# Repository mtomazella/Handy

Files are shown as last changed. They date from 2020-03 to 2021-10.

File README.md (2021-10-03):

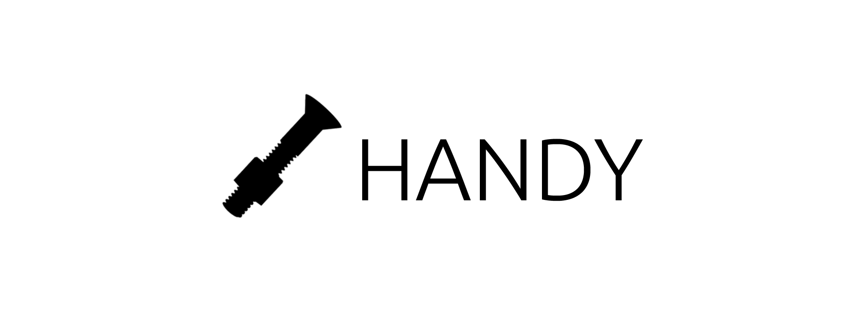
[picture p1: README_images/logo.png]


<p align="center"> Prótese são muito caras, frequentemente fazendo com que pessoas com membros amputados não tenham condições de pagar por uma. O objetivo do projeto é criar uma solução barata para o cliente, a fim de que possa melhorar sua qualidade de vida até conseguir uma prótese mais tecnológica. </p>

### [Documentação](https://github.com/MatheusTomazella/Handy/blob/master/Documentação/Documentação.pdf)
### [Repositório API](https://github.com/matheustomazella/pinus)  
### [Repositório Web](https://github.com/MatheusTomazella/Handy-Web)
### [Repositório Mobile](https://github.com/matheustomazella/handy-mobile)
### [Repositório Desktop](https://github.com/matheustomazella/handy-desktop)
### [Repositório Firmware](https://github.com/MatheusTomazella/Handy-Firmware)
### [Trello](https://trello.com/b/jp3Bz9N3/tcc)

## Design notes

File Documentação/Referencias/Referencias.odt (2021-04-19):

Hand Design:

https://github.com/ikkalebob/NM-bionic-hand

https://www.youtube.com/channel/UCkUD_8b1JoTL2ipOVtxfNKw

Muscle Contraction Sensor

https://www.mdpi.com/1424-8220/18/8/2553/htm

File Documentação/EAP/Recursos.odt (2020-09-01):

# Ferramentas

• Impressora 3d;

• Multímetro.

# Recursos Construção Mecânica

• 9x Parafuso M4 cabeça chata 20mm;

• 1x Parafuso M4 cabeça chata 26mm;

• 1x Parafuso M4 cabeça chata 90mm;

• ?m Filamento ??

# Recursos Construção Eletrônica

N = número de controles

• (N+1)x Arduino Mini 3.3v (modelo Pro opcional);

• (N+1)x Placa de proteção de bateria 18650 BMS 1 S 3 A 4.2v;

• (N+1)x Módulo de rádio nRF24;

• 1x Módulo Bluetooth hc 06 ou hc 05;

• 5x Motor DC;

• 5x Transistor NPN que suporte 8.4v e 2A (opção: BC368);

• 3x Resistor 220Ohms;

• (N+1)x Conector para fonte de celular;

• Chave Táctil (Push Button);

• Baterias Li-ion 18650;

• Conversor USB Serial TTL.

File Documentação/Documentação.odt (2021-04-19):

HANDY

DOCUMENTAÇÃO

v 2020.09.20

Matheus Tomazella

Luiz Felipe Costa Soares

Eduardo Gomes Heleno

# 1 TERMOS DE ABERTURA

## 1.1 JUSTIFICATIVA DO PROJETO

Muitas vezes prótese são muito caras, levando pessoas com membros amputados a não terem condições de pagar por uma. O objetivo do projeto é criar uma solução barata para o cliente, a fim de que possa melhorar sua qualidade de vida até conseguir uma prótese mais tecnológica.

## 1.2 DESCRIÇÃO DO PROJETO

A ideia principal dessa prótese é a acessibilidade, possibilitando que mais camadas da sociedade tenham condições de possuir uma prótese para seus membros amputados. O produto é pensado para confecção em impressoras 3d, porém pode ser construído segundo a vontade do cliente, e deve ser controlado por movimentos de outras partes do corpo.

Uma página web será criada para compartilhar informações sobre o produto e permitir que interessados se comuniquem com os criadores.

O produto possuirá um software para desktop, para acessar os dados enviados por interessados no projeto por meio do site e um software mobile configuração da prótese.

## 1.3 GERENTE DO PROJETO

MATHEUS TOMAZELLA

### 1.3.1 Nível de Autoridade

O gerente de projeto deve ter autoridade para coordenar recursos financeiros e humanos disponibilizados, a fim de concluir o projeto.

## 1.4 PATROCINADOR

Grupo responsável pelo projeto.

## 1.5 PARTES INTERESSADAS

1. Cliente;
2. Projetista;
3. Designer;
4. Programador.

## 1.6 RESTRIÇÕES

1. Não existe um orçamento máximo fixo para o projeto, porém deve usar o mínimo possível de recursos financeiros;
2. O projeto deve possuir uma versão totalmente funcional até o final do ano de 2021.

## 1.7 PREMISSAS

1. Deve priorizar um produto final barato;
2. O produto deve poder ser construído pelo cliente.

## 1.8 AUTORIZAÇÃO DO PROJETO

Data: 01 de Setembro de 2020

______________________________________

Matheus Tomazella

# 2 DETALHAMENTO DE REQUISITOS

## 2.1 ENGENHARIA DA PRÓTESE

### 2.1.1 Funcionamento da prótese

O movimento da prótese é baseado em fios que correm entre os dedos, ligando a parte mais extrema de cada dedo com seu correspondente atuador. Uma vez que o atuador puxa o fio, a ponta do dedo será puxada e o levará a se dobrar contra a palma, assim como uma mão biológica.

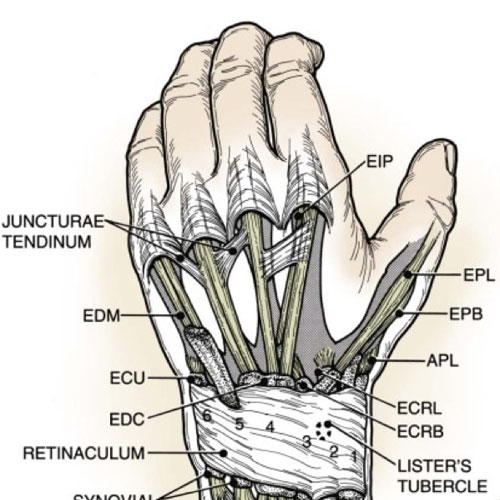
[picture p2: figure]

Fonte: http://feliperoth.com.br/traumatologia-da-mao/lesao-de-tendao/#

Na parte contrária a palma da mão, um material elástico será responsável por mover os dedos para suas posições originais assim que a força aplicada pelos atuadores parar de agir.

### 2.1.2 Projetos

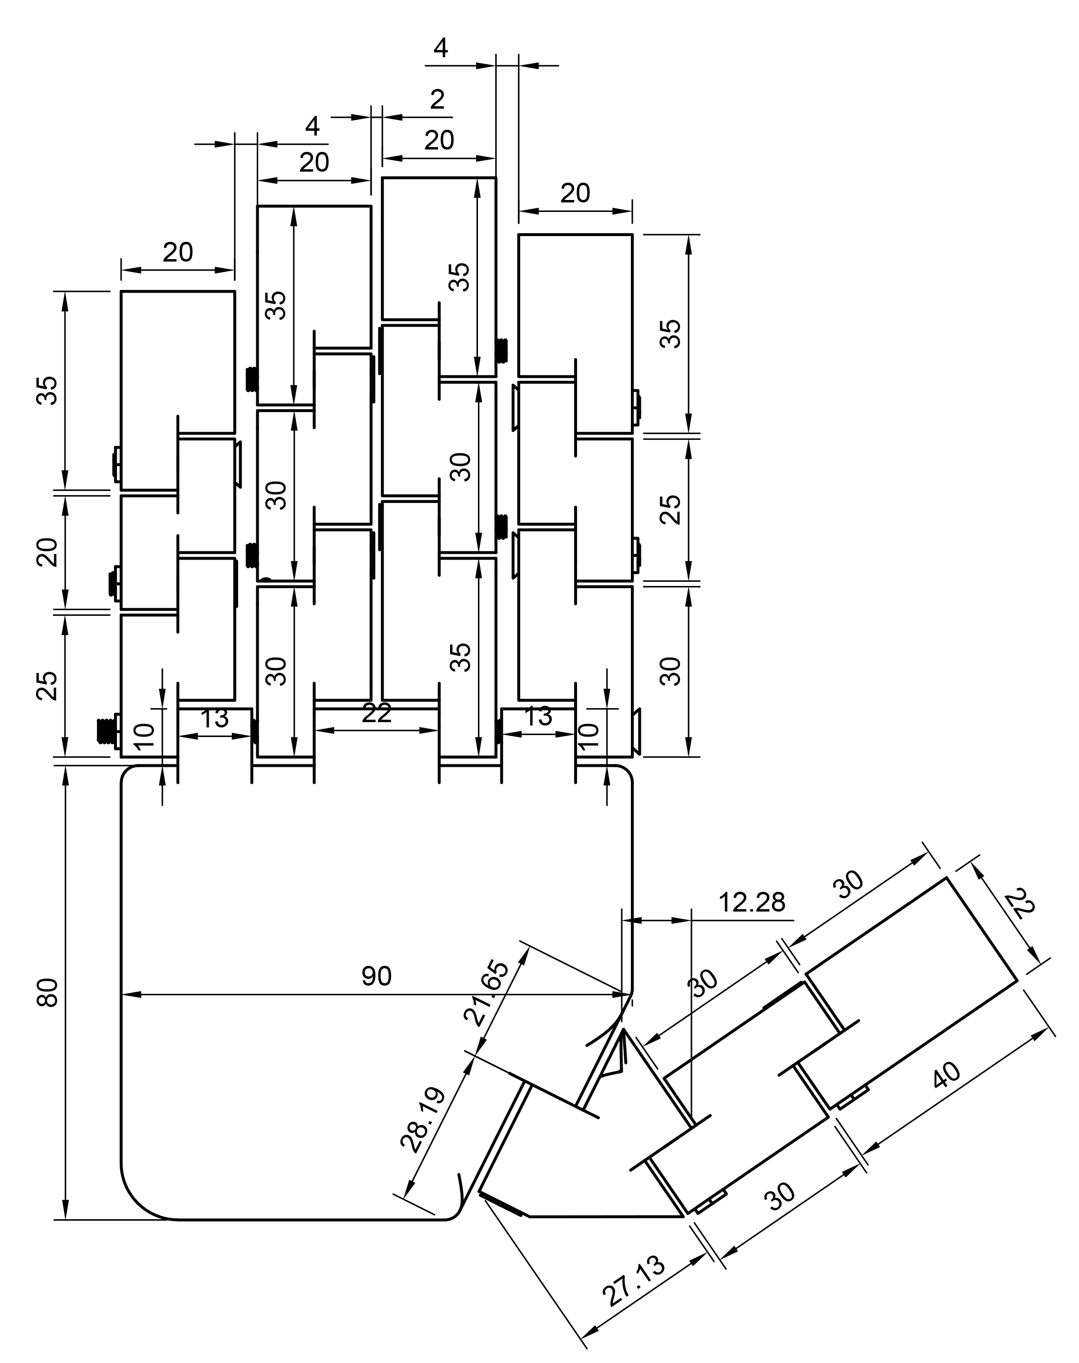
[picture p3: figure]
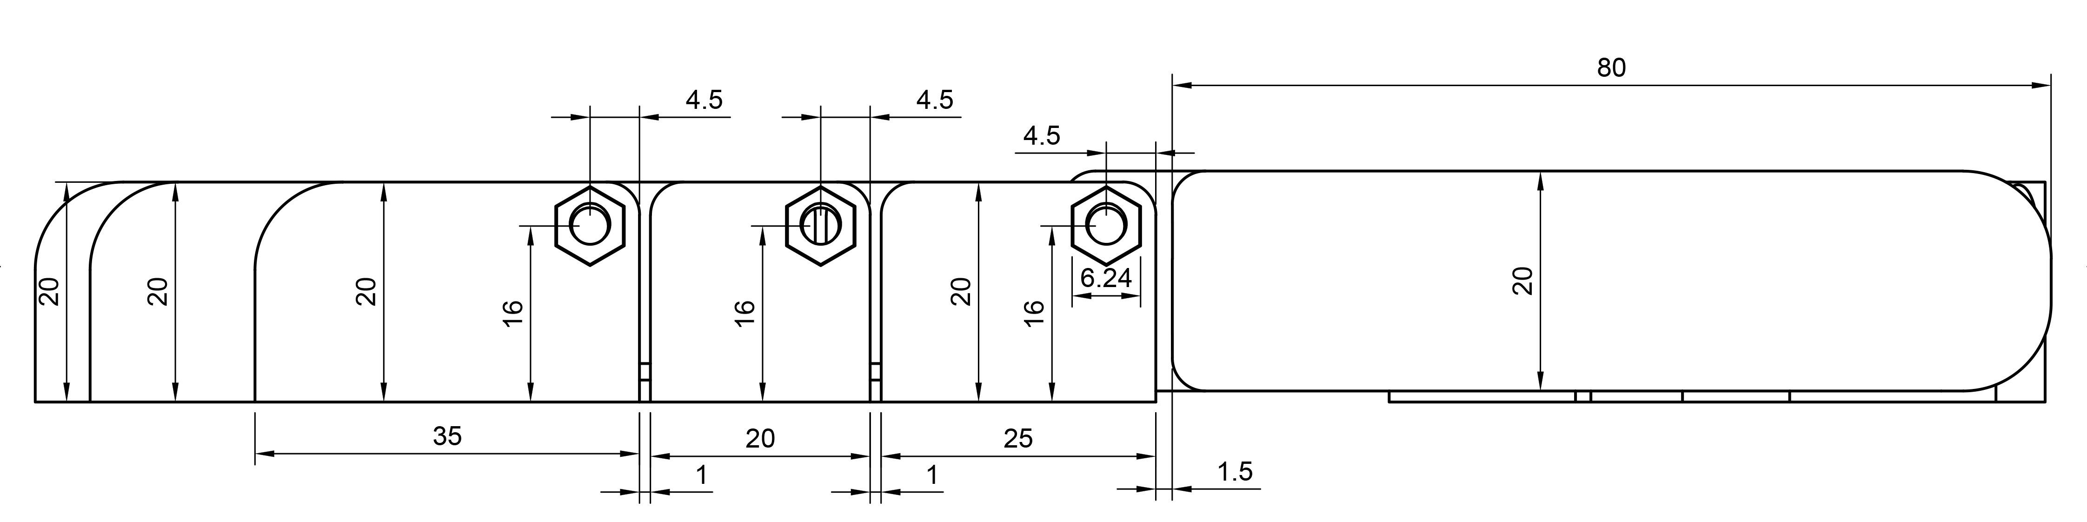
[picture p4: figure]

Unidade: mm

POV: Cima

Parafuso ideal para juntas entre as falanges

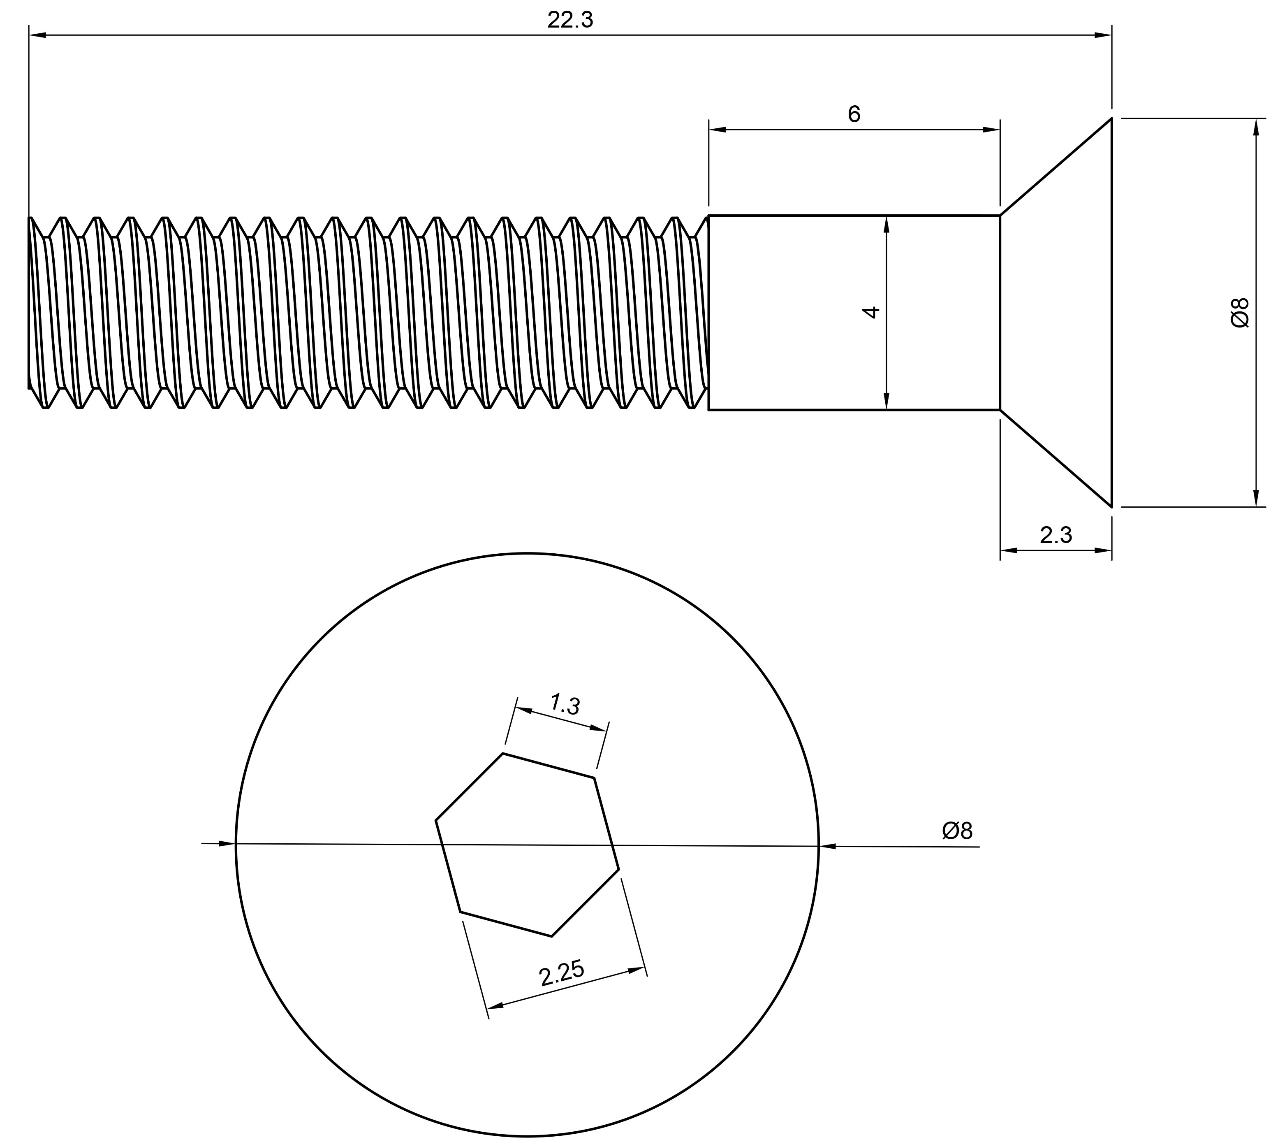
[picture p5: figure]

Parafuso Allen cabeça chata M4 de 20mm de comprimento

Unidade: mm

Parafuso ideal para a junta entre metacarpo e falanges do dedo polegar e a junta entre metacarpo e carpo do dedo polegar

Parafuso Allen cabeça chata M4 de 90mm de comprimento.

Unidade: mm

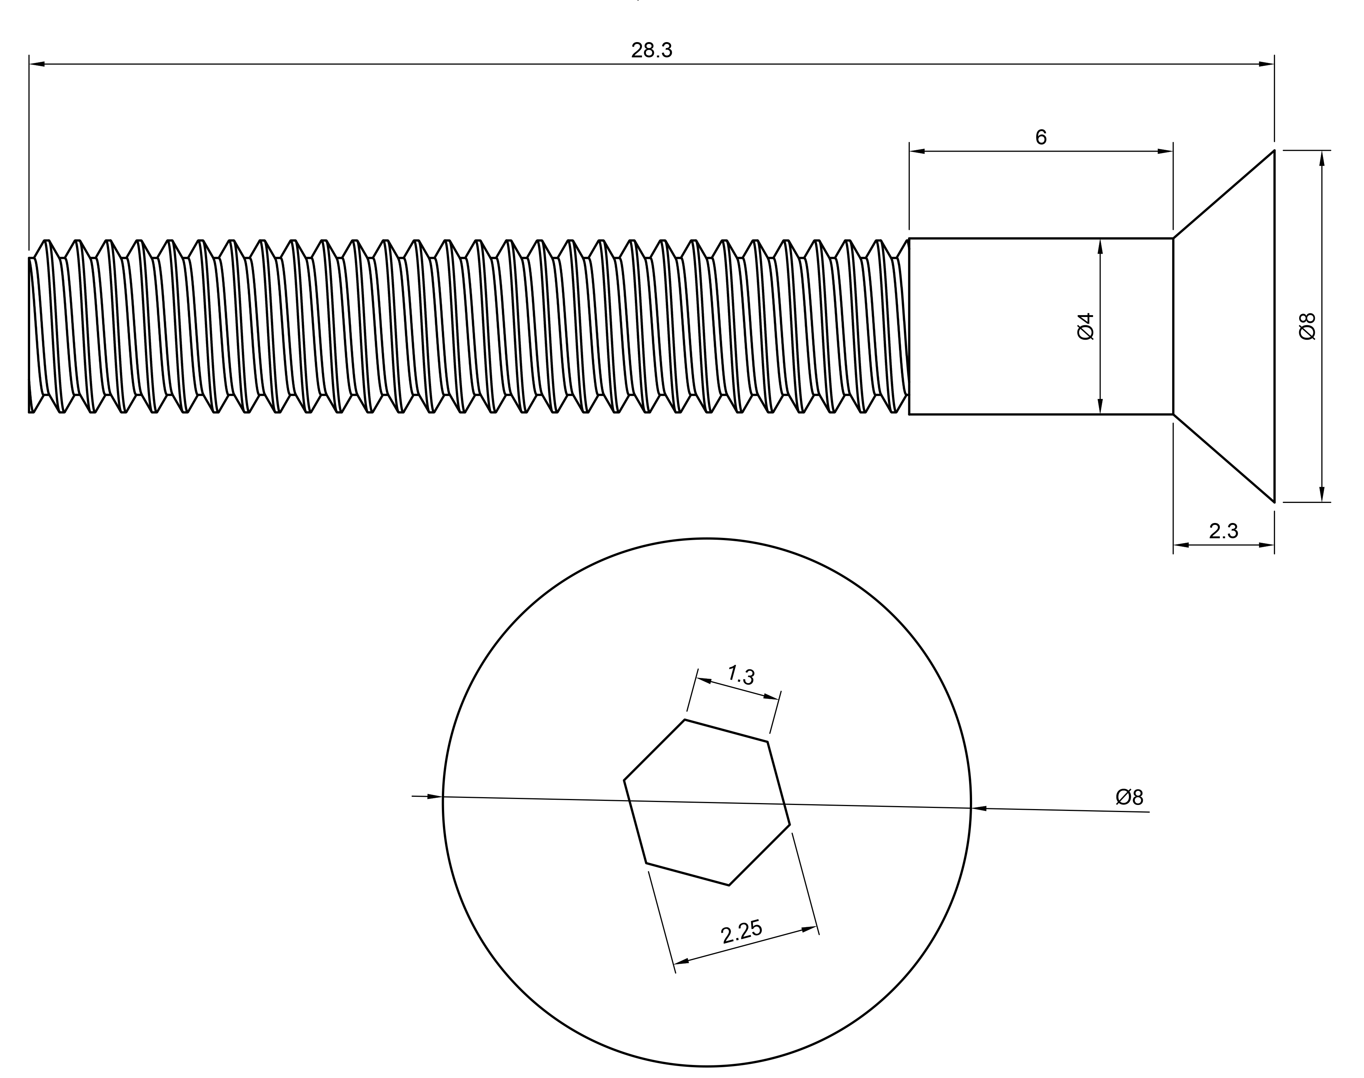
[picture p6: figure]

Parafuso ideal para as juntas entre metacarpo e falanges

Parafuso Allen cabeça chata M4 de 90mm de comprimento.

Diferente das demais juntas, as juntas entre metacarpo e falanges compartilham o mesmo parafuso.

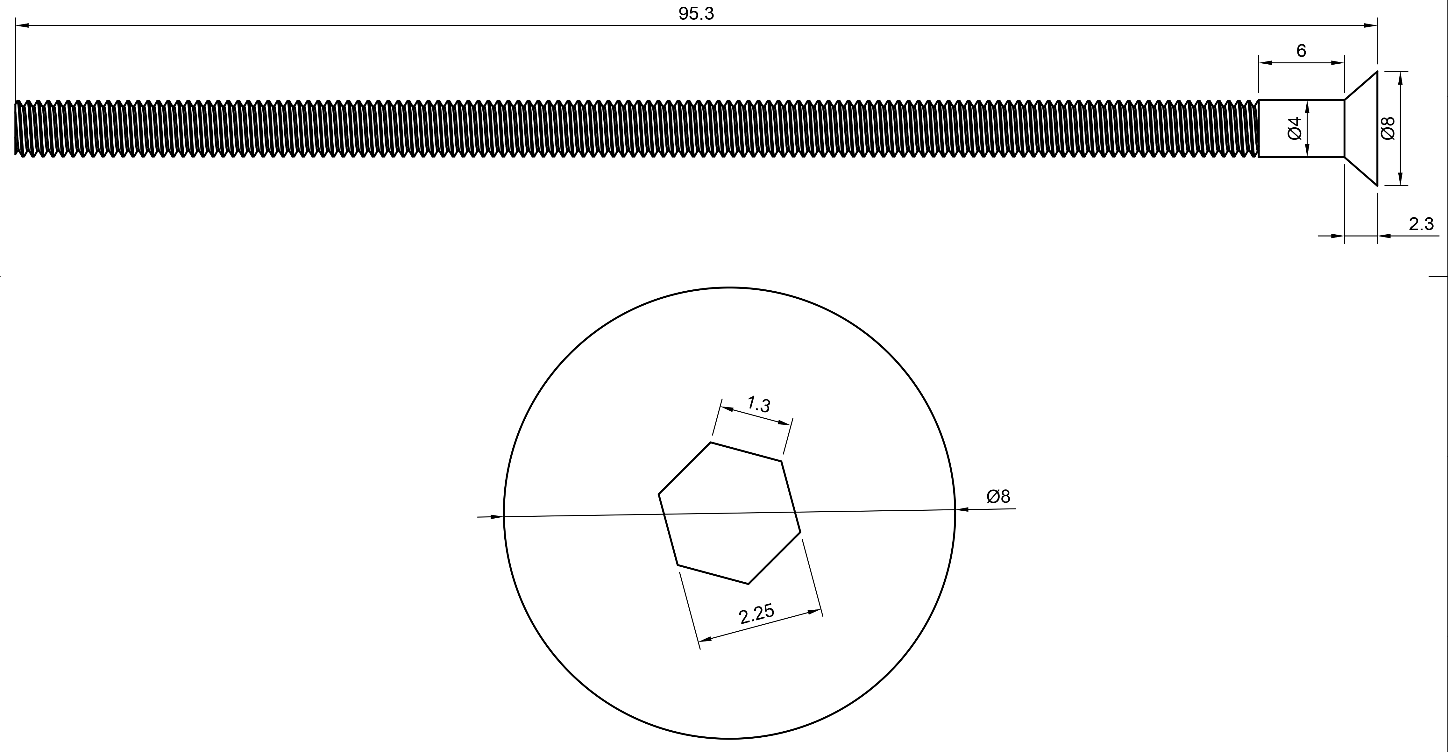
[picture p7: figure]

Unidade: mm

Porca ideal para todas as juntas

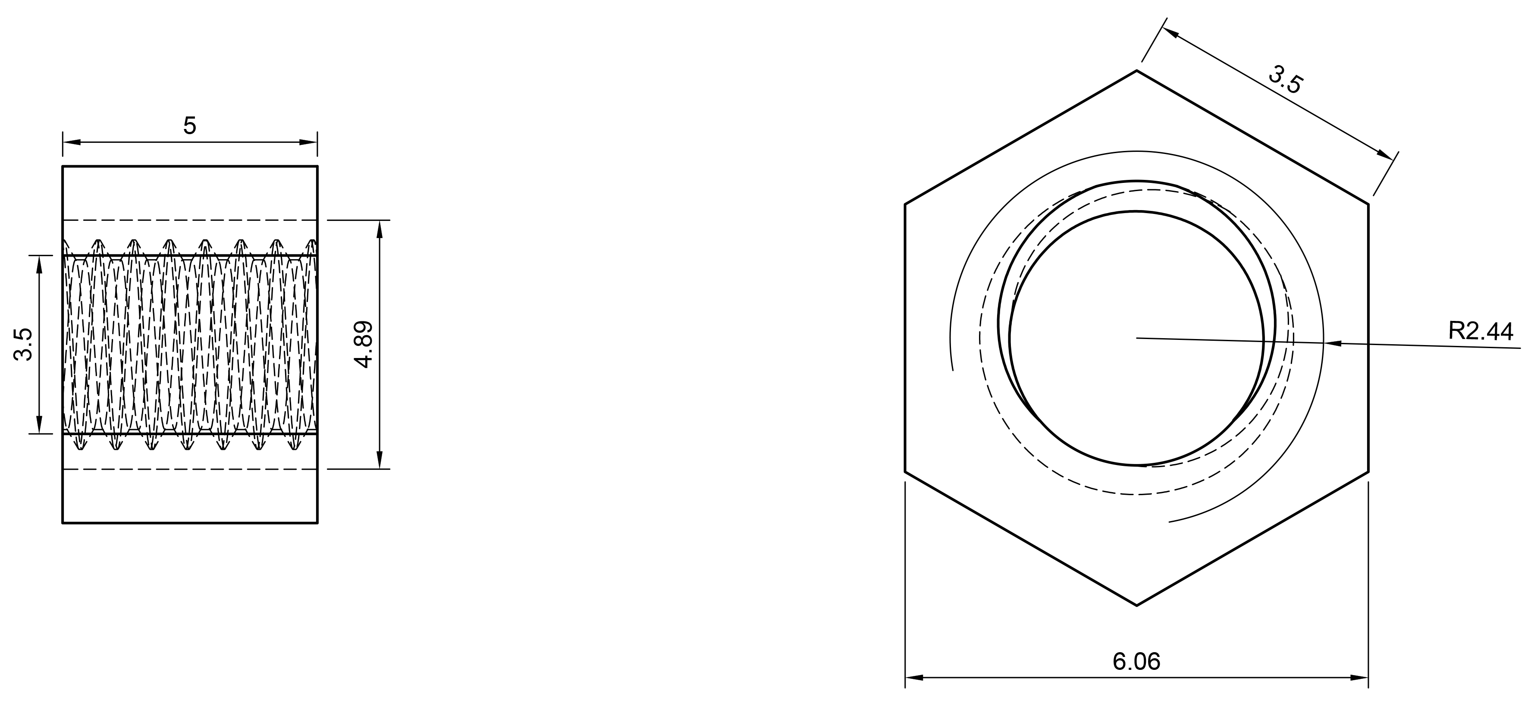
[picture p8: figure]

Porca Parlock M4 – Projeto simplificado

Tabelas relativas aos parafusos e porcas

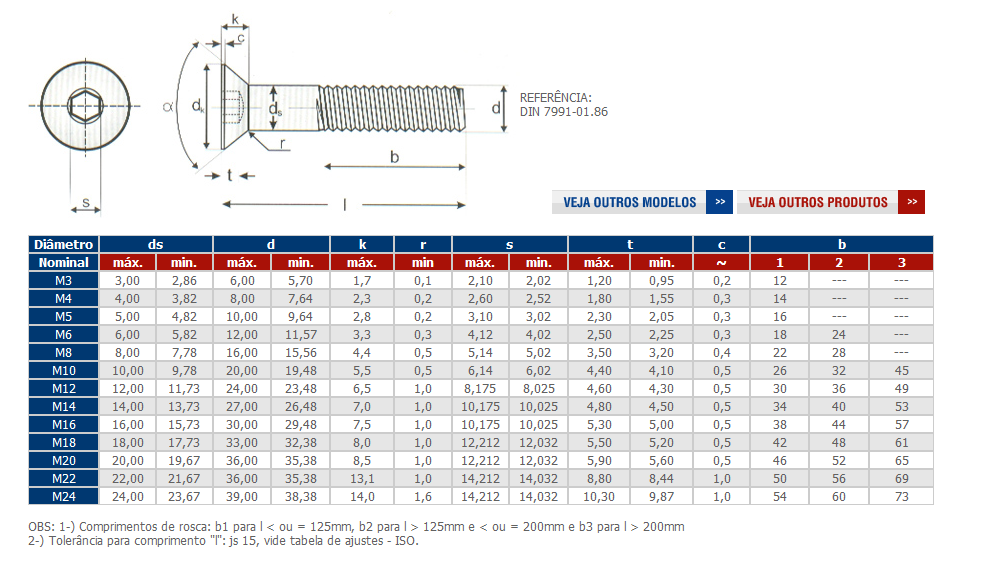
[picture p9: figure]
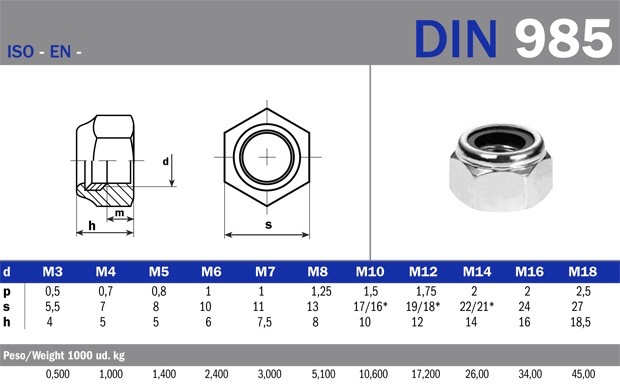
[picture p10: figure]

### 2.1.3 Imagens Renderizadas

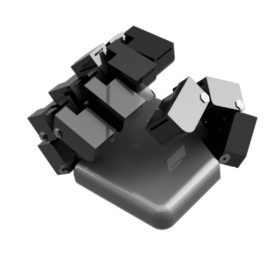
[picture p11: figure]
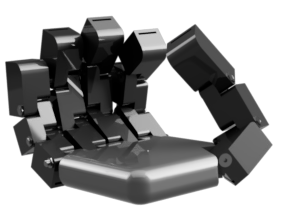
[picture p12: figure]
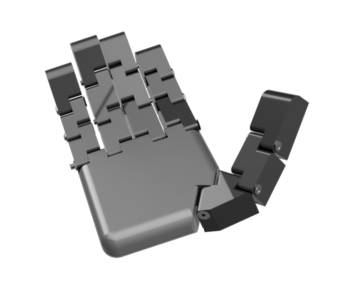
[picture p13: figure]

### 2.1.4 Funcionamento do Circuito

O circuito pode ser dividido em três principais partes: Sensores, Controladores e Atuadores. Os Sensores tem como função captar os comandos do usuário, enviando-os para o Controlador, que processa os dados e comanda os Atuadores, os quais são os componentes responsáveis por movimentar a prótese.

Os eletrônicos específicos podem ser definidos pelo usuário final, porém o projeto original utiliza Servo Motores como Atuadores e sensores de pressão, usando como Controlador um ESP32s.

Energia

Em produto móvel uma parte fundamental é a autonomia, sendo de extrema importância que o produto tenha uma capacidade energética condizente com seu uso. Pensando nestes pontos, as baterias mais condizentes com as necessidades foram as células de Li-Po, por possuírem uma grande densidade energética.

Existem problemas com esta escolha, porém, uma vez que baterias de lítio são instáveis em certas situações. Para diminuir os riscos, o sistema de encaixe deverá ser fácil de remover a fim de reduzir quaisquer danos.

Para o funcionamento dos eletrônicos, é necessária uma voltagem de 6V, sendo assim necessária a utilização de uma bateria de 7,2V e um transformador.

A recarga das baterias pode ser feita tanto por meio de carregadores de bateria de li-po. É importante notar que baterias desse tipo precisam de uma “carga balanceada” para garantir que todas as células possuam a mesma tensão.

### 2.1.5 Projeto do Circuito

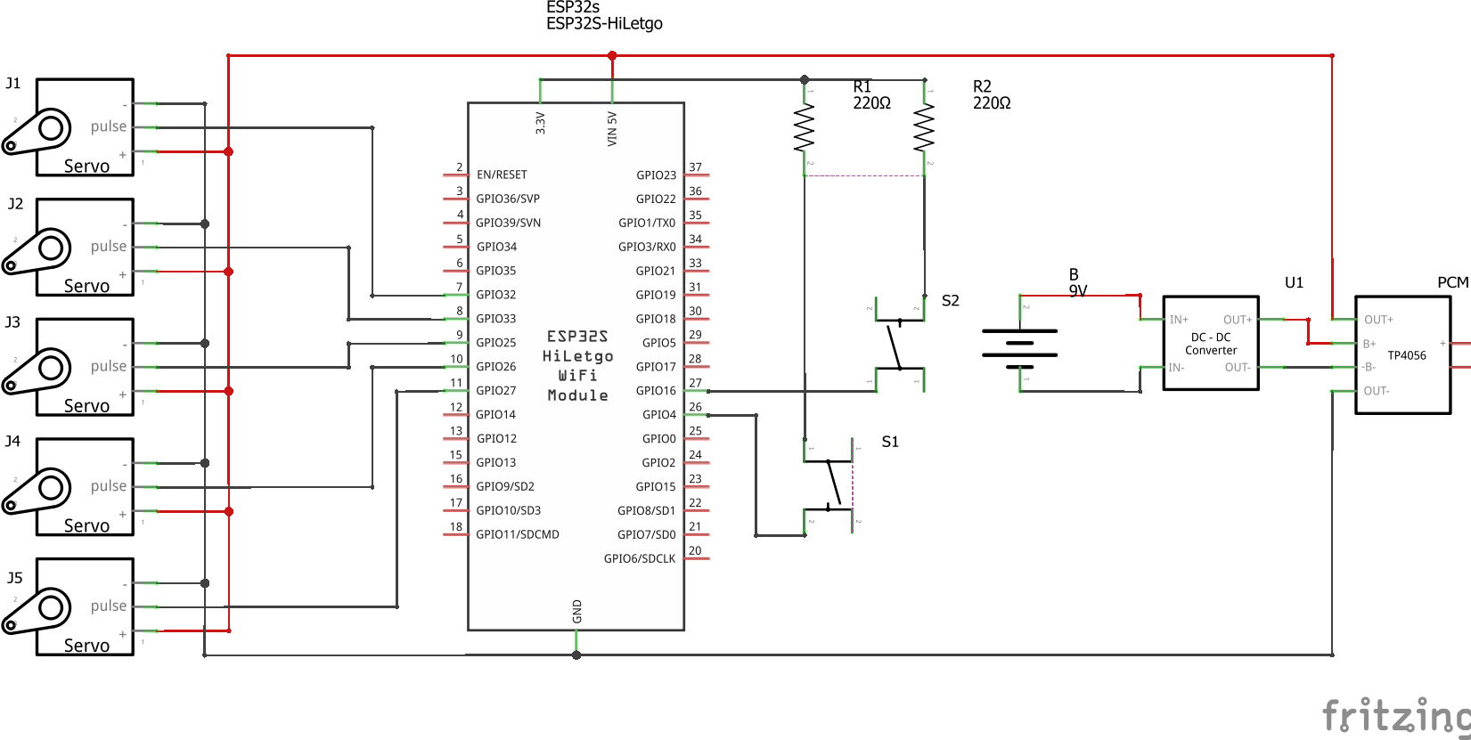
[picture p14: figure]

### 2.1.7 Requisitos Funcionais

1. Deve ter a capacidade de segurar objetos;
2. Deve funcionar com uma fonte de energia móvel;
3. Deve seguir os modos de funcionamento dados pelo usuário por meio do aplicativo mobile.

## 2.2 SOFTWARE WEB

A parte web do projeto terá como função explicar sobre o produto, além de permitir a comunicação entre o interessado e os criadores.

Será composta de explicações sobre o projeto, como funcionamento e motivações, instruções de montagem, imagens de produtos prontos e um chat para que aqueles com problemas possam tirar dúvidas com um time de suporte.

### 2.2.1 Requisitos Funcionais

1. Deve ter chat para conversa com o time de suporte;
2. Deve possuir uma galeria com imagens do produto;
3. Deve conter informações sobre montagem e funcionamento.

### 2.2.2 Requisitos Não Funcionais

1. Deve funcionar em qualquer navegador a partir de uma versão 2020, incluindo navegadores de aparelhos móveis.
2. Deve ser desenvolvido com base em HTML, CSS, JavaScript (Puro, Jquery e Node.js).

## 2.3 SOFTWARE DESKTOP

A parte Desktop do projeto tem como alvo a criação de um sistema de gerenciamento para o time do produto, contando com um sistema para gerenciamento lojas que disponibilizam cada um dos componentes do sistema e um sistema de chat com o usuário do site.

### 2.3.1 Requisitos Funcionais

1. Deve ter um sistema de gerenciamento de fornecedores de cada componente;
2. Deve suprir a necessidade de um mecanismo de contato com o usuário do site por meio de um sistema de chat;

### 2.3.2 Requisitos Não Funcionais

1. Deve funcionar no sistema Windows 10;
2. Deve ser desenvolvido em Node.js/Electron.

## 2.4 SOFTWARE MOBILE

O sistema Mobile do projeto será composto de um aplicativo que se conectará com com o produto e poderá controlá-lo por Bluetooth.

Contará com um sistema de modos que definem como a prótese deve se mover. Cada modo confere dois estados que podem ser alternados pelo usuário usando os sensores da prótese.

### 2.4.1 Requisitos Funcionais

1. Deve poder se conectar com o sistema da prótese por Bluetooth;
2. Deve poder informar o hardware da prótese sobre como se mover, dado o modo definido pelo usuário.

### 2.4.2 Requisitos Não Funcionais

1. Deve ser compatível com o sistema Android;
2. Deve estar disponível na Play Store;
3. Deve ser desenvolvido em React Native.

## 2.5 BANCO DE DADOS

O banco de dados do sistema será responsável por armazenar as informações do usuário no site, fazer a ligação do chat entre o site e o aplicativo Desktop, também armazenando estas informações, e armazenar os dados do sistema de gerenciamento presente no sistema para Windows.

### 2.5.1 Requisitos Funcionais

1. Deve armazenar as informações do usuário;
2. Deve fazer a ligação do chat entre usuário web e time no Desktop;
3. Deve armazenar as informações de gerenciamento da solução Desktop.

### 2.5.2 Requisitos Não Funcionais

1. Deve ser desenvolvido com o sistema mySQL;

### 2.5.3 Diagramas

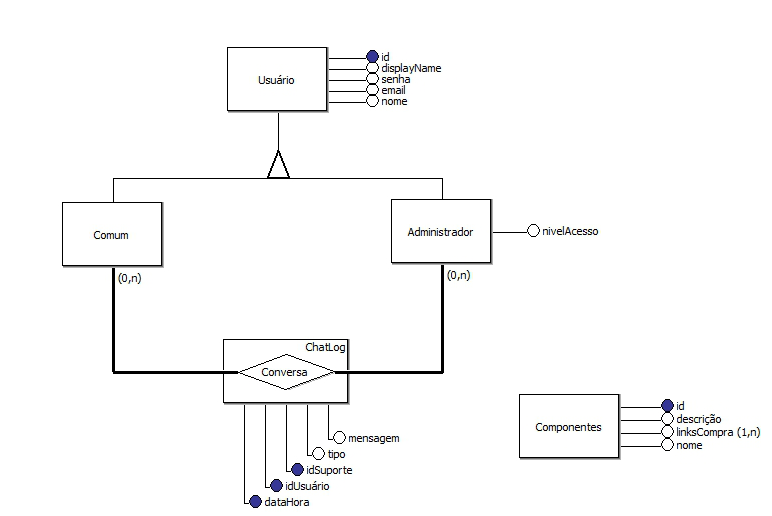
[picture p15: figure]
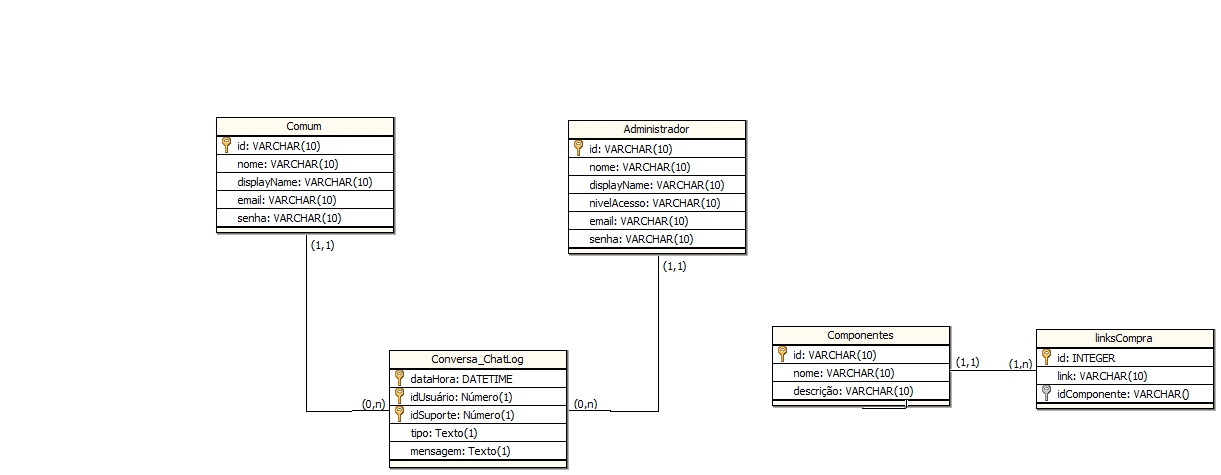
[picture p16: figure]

# 3 CASOS DE USO

## 3.1 PINUS ( API )

Sendo a API desenvolvida em Node.js a base do funcionamento das partes Web e Desktop, essa sessão servirá para ambos os serviços.

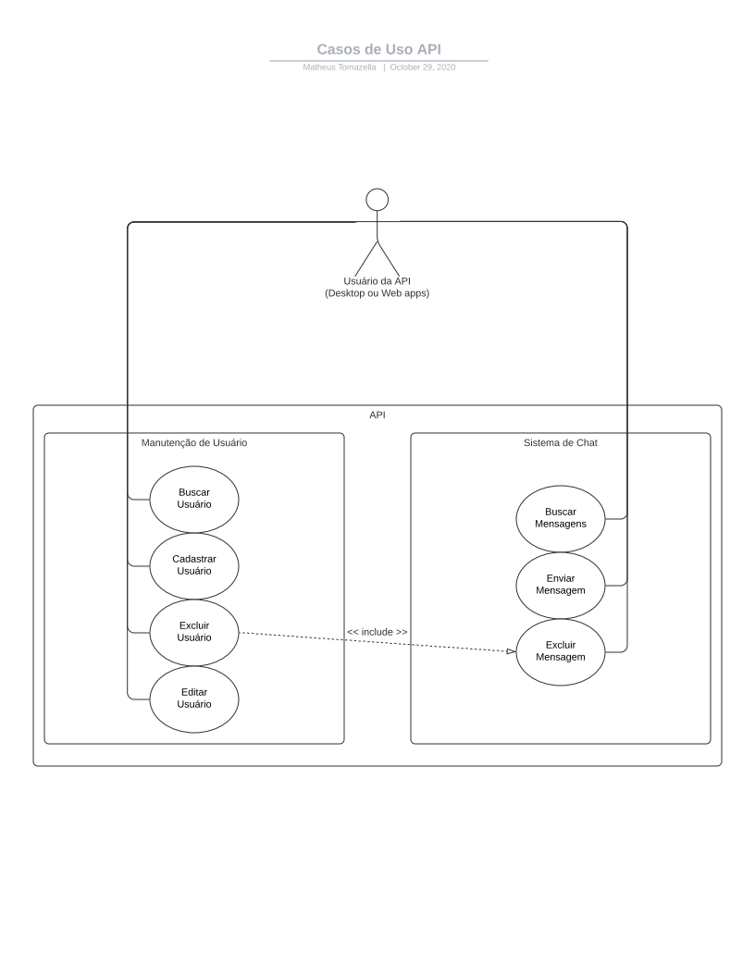
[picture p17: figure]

### 3.1.1 Cadastrar Usuário / Admin

1. O usuário se conecta à API por um dos canais ( HTTP / WebSocket );
2. O usuário solicita o cadastro, enviando os seguintes dados, sendo todos obrigatórios:
  - Nome de exibição ( texto );
  - Nome ( texto );
  - E-mail ( texto );
  - Senha ( texto );
  - Nível de acesso ( número ) ( apenas no caso de cadastro de Admin ).
3. O sistema valida as informações;
4. Caso as informações sejam válidas, o sistema cadastra o usuário no banco de dados e retorna as informações no formato de objeto; Caso as informações sejam inválidas, o sistema retorna um erro;

### 3.1.2 Buscar Usuário / Admin

1. O usuário se conecta à API por um dos canais ( HTTP / WebSocket );
2. O usuário solicita uma busca, enviando os identificadores do registro prontamente;
3. O sistema valida as informações;
4. Caso as informações sejam inválidas, o sistema retorna um erro;
5. Caso as informações sejam válidas, o sistema faz uma busca no banco de dados usando os identificadores informados;
6. O sistema retorna uma lista contendo os objetos de cada resultado da busca. Os objetos são compostos do nome da coluna, seguido pelo valor na linha.

### 3.1.3 Alterar Usuário / Admin

1. O usuário se conecta à API por um dos canais ( HTTP / WebSocket );
2. O usuário solicita uma alteração em determinado registro, enviando um objeto com a seguinte formação:
  {
    “identifier”: {
      “[ coluna da tabela ]”: “[ valor atual ]”,
    },
    “password”: “[ senha atual ]”,
    “update”: {
      “[ coluna da tabela ]”: “[ novo valor ]”,
    }
  }
3. O sistema executa a operação no banco de dados;
4. Caso haja um erro, o sistema retorna o erro;
5. Em caso de sucesso, o sistema executa uma BUSCA ( 3.1.2 ) e retorna seu resultado.

### 3.1.4 Exlcuir Usuário / Admin

1. O usuário se conecta à API por um dos canais ( HTTP / WebSocket );
2. O usuário solicita uma exclusão em determinado registro, enviando um objeto com a seguinte formação:

{

“identifier”: {

“[ coluna da tabela ]”: “[ valor atual ]”

},

“password”: “[ senha atual ]”,

  }
3. O sistema executa a operação no banco de dados;
4. Caso haja um erro, o sistema retorna o erro;
5. Em caso de sucesso, retorna uma confirmação de conclusão.

### 3.1.5 Enviar Mensagem

1. O usuário se conecta à API por um dos canais ( HTTP / WebSocket );
2. O usuário solicita o enviamento de uma mensagem, enviando um objeto com a seguinte formação:
  {
    “idAdmin”: [ código do admin ],
    “idUser”: [ código do usuário ],
    “datetime”: null, //será preenchido pela API
    “sender”: “[ admin / user ]”, //o tipo de usuário que está mandando a mensagem
    “type”: “[ text / image ]”, //o tipo da mensagem,
    “text”: “[ texto ]”, //Opcional
    “image”: “[ imagem ]” //Opcional
  }
3. O sistema adiciona a mensagem ao banco de dados;
4. Caso haja um erro, o erro é retornado;
5. Em caso de sucesso, o sistema envia uma confirmação ao usuário;
6. O sistema busca nas sessões ativas o destinatário da mensagem;
7. Caso o destinatário esteja “logado”, o sistema envia a mensagem. Caso não esteja, a mensagem será retornada junto com o restante no momento da inicialização do “chat”.

### 3.1.6 Buscar Mensagem

1. O usuário se conecta à API por um dos canais ( HTTP / WebSocket );
2. O usuário solicita a busca de mensagens, enviando as informações que as identificam;
3. O sistema faz uma busca no banco de dados, usando as informações para identificá-las ;
4. Caso haja um erro, o sistema retorna o erro;
5. Em caso de sucesso, o sistema retorna uma lista contendo os objetos das mensagens.

# 4 DEFINIÇÃO DE RECURSOS

## 4.1 STAKEHOLDERS

NOME | RESPONSABILIDADES | E-MAIL
Matheus Tomazella | Engenharia, Documentação, API | matheus250504@gmail.com
Luiz Felipe Costa Soares | Web, Firmware | lfcsoares04@gmail.com
Eduardo Gomes Heleno | Mobile | Eduardo.gheleno@gmail.com
Lucas Beretta Alvetti | Desktop | lucasberettaalvetti@gmail.com

## 4.2 LISTA DE RECURSOS DE CONSTRUÇÃO

### 4.2.1 Ferramentas

- Impressora 3d;
- Multímetro.

## 4.2.2 Recursos Construção Mecânica

- 9x Parafuso M4 cabeça chata 20mm;
- 1x Parafuso M4 cabeça chata 26mm;
- 1x Parafuso M4 cabeça chata 90mm;
- ?m Filamento ??.

### 4.2.3 Recursos Construção Eletrônica

- 1x Esp32s;
- 10x Servo Motor;
- 1x Circuito de proteção;
- 2x Sensor de contração muscular;
- 2x Resistor 220Ω;
- 1x Bateria Li-po 7.2v

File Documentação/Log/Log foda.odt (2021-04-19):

Log Semanal

?? - 2021-03-01

Engenharia Eletrônica: Levantamento dos preços dos componentes.

2021-03-02 - 2021-03-08

Compras: Comprado 2xEsp32s e 1x Esp nodemcu V.3 na semana anterior. Pacotes chegaram na Sexta-feira.

Firmware: Completo: Gpio. Em execução: Hand, Mode, HardwareController

2021-03-09 – 2021-03-15

Firmware: Local e BLE completos

Mobile: Design das páginas no Figma.

2021-03-08 – 2021-03-22

Engenharia: Protótipo de madeira

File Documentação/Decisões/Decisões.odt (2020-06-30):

HANDY

DECISÕES

v 0.2020.06.29

Matheus Tomazella

Luiz Felipe Souza Soares

# 1 TRANSMISSÃO DE DADOS

É importante para o projeto que a transmissão de dados não atrapalhe a movimentação de quem usa o produto, uma vez que este será acoplado ao cliente. A fim de não causar desconforto com fios passando pelas roupas para ligar o controle aos atuadores, decidimos que a melhor solução seria uma conexão sem fios por meio de Bluetooth, uma vez que já seria útil para a conexão com o aplicativo para smartfones que seria desenvolvido.

Após uma pesquisa sobre a conexão Bluetooth nos deparamos com um problema: é muito difícil conectar mais de um dispositivo de controle a um aparelho, pois seria necessário que ambos os dispositivos fossem compartíveis com Bluetooth 5.0. A solução foi mudar o protocolo de comunicação parcialmente.

Durante a pesquisa nos deparamos com um módulo de código nRF24, um componente de conexão wireless baseado em radiofrequência 2.4GHz, o mesmo comprimento de onda do Bluetooth. É um módulo barato que nos permitiria conectar o controle ao mesmo tempo que o módulo Bluetooth estivesse conectado ao dispositivo móvel.

# 2 MICROCONTROLADORES

Para o sucesso do projeto, percebemos que seria necessário a utilização de módulos de microcontroladores prontos, pois não poderíamos fornecer nossos próprios componentes para aqueles interessados, uma vez que o principal foco do projeto é que aqueles que precisam de uma de nossas mãos possam construir uma por si mesmos a partir dos nossos arquivos e instruções.

Partimos então em busca de um módulo barato e comum, capaz de realizar tudo o que era necessário para operar a prótese.

Um dos padrões de placa de microcontrolador mais conhecido é o Arduino, uma marca que conta com vários modelos de placas com hardware open-souce e centenas de marcas de placas genéricas pelo mundo. São componentes, no geral, baratos e fáceis de conseguir.

Provavelmente a placa mais conhecida da linha é a Uno, baseada no microcontrolador ATmega328P. Esta placa, porém é muito grande para ser conveniente ao usuário, por tanto nossa próxima opção foi a Nano, uma placa baseada no mesmo microcontrolador, porém muito menor.

Depois de estudar a placa e calcular a quantidade de pinos necessários para colocar os módulos de conexão necessários, concluímos que o ATmega328P seria suficiente para nosso uso, uma vez que, de seus 14 pinos padrão digital, 6 ficariam livres para serem usados pelos atuadores.

Consideramos também utilizar a placa Mini, que também utiliza o mesmo microcontrolador. Concluímos que sua versão de 5 volts seria viável, porém esta versão é consideravelmente difícil de encontrar e sua versão de 3.3 volts causaria um aumento significativo na complexidade do circuito.

# 3 BATERIAS

## 3.1 TIPO DA BATERIA

Em produto móvel uma parte fundamental é a autonomia. É de extrema importância que o produto tenha uma capacidade energética condizente com seu uso, porém também é muito importante que esta energia seja armazenada de forma conveniente e segura.

Pensando nestes pontos, a seguir está uma relação entre algumas características de alguns tipos de bateria.

Não to querendo fazer isso agora, deixa pra depois.

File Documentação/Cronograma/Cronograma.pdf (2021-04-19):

# Projeto: Handy

ATIVIDADE | INÍCIO | Predecessoras | Recursos | PERÍODOS
1 2 3 4 5 6 7 8 9 10 11 12 13 14 15 16 17 18 19 20 21 22 23 24 25 26 27 28 29 30 31 32 33 34 35 36 37 38 39 40 41 42 43 44 45 46 47 48 49 50 51 52
1. Preparação/Planejamento | 1 | 5 | | | - | 100%
1.1 Criação dos Termos de Abertura | 1 | 1 | | Resp. Documentação | - | 100%
1.2 Criação do Escopo | 2 | 1 | | Resp. Documentação | | 100%
1.3 Criação da Estrutura Analítica do Projeto | 3 | 1 | | Resp. Documentação | - | 100%
1.4 Criação do Cronograma do Projeto | 5 | 1 | 1.3 | Resp. Documentação | - | 100%
1.5 Criação dos Modelos Lógicos (DER, MER, UML, Casos de Uso) | 4 | 1 | | Resp. Documentação | - | 100%
1.6 Criação do Documento de Requisitos | 1 | 5 | 1.1; 1.2; 1.3; 1.4; 1.5 | Resp. Documentação | - | 100%

### 2. Design 6 11 -81%

2.1 Criar design detalhado da parte mecânica 6 11 -44%
2.1.1 Criar design base | 6 | 2 | | Resp. Eng. Mecânica | - | 100%
2.1.2 Criar canais para elásticos | 8 | 1 | 2.1.1 | Resp. Eng. Mecânica | - | 100%
2.1.3 Definir porcas e parafusos usados | 9 | 1 | 2.1.1 | Resp. Eng. Mecânica | - | 100%
2.1.4 Criar encaixes para as porcas e parafusos | 9 | 1 | 2.1.1 | Resp. Eng. Mecânica | - | 100%
2.1.5 Modelar canais para os fios | 10 | 1 | 2.1.1 | Resp. Eng. Mecânica | - | 0%
2.1.6 Modelar encaixe para o braço | 11 | 2 | 2.1.1 | Resp. Eng. Mecânica | - | 0%
2.1.7 Definir como os atuadores devem funcionar | 13 | 3 | 2.1.1 | Resp. Eng. Mecânica | - | 0%
2.1.8 Definir como guardar os eletrônicos | 16 | 1 | 2.1.1 | Resp. Eng. Mecânica | - | 0%
2.1.9 Criar peça que segura o elástico | 16 | 1 | 2.1.1 | Resp. Eng. Mecânica | - | 0%
2.2 Criar circuito eletrônico | 6 | 4 | | | - | 100%
2.2.1 Definir forma de transmissão de dados | 6 | 1 | | Resp. Eng. Eletrônica | - | 100%
2.2.2 Definir componentes | 7 | 1 | 2.2.1 | Resp. Eng. Eletrônica | - | 100%
2.2.3 Criar diagrama de circuito | 8 | 1 | 2.2.2 | Resp. Eng. Eletrônica | - | 100%
2.2.4 Criar lista de componentes com links de compra e preços | 9 | 1 | 2.2.2 | Resp. Eng. Eletrônica | - | 100%
2.3 Criar design base das telas 6 5 -100% 2.3.1 Design Web 6 2 -100%
2.3.1.1 Design Tela Inicial | 6 | 1 | | Grupo | - | 100%
2.3.1.2 Design Galeria | 6 | 1 | | Grupo | - | 100%
2.3.1.3 Design Login e Cadastro | 7 | 1 | | Grupo | - | 100%
2.3.1.4 Design Chat | 7 | 1 | | Grupo | - | 100%
2.3.2 Design Desktop | 8 | 2 | | | - | 100%
2.3.2.1 Design Gerenciamento de Fornecedores | 8 | 1 | | Grupo | - | 100%
2.3.2.3 Design Login e Cadastro | 8 | 1 | | Grupo | - | 100%
2.3.2.4 Design Chat | 9 | 1 | | Grupo | - | 100%
2.3.2.5 Design Gerenciamento de Usuários | 9 | 1 | | Grupo | | 10000%
2.3.3 Design Mobile | 10 | 1 | | | - | 100%
2.3.3.1 Design Tela inicial e Controles | 10 | 1 | | Grupo | - | 100%
3. Implementação | 17 | 1 | | | 210 | 100%
3.1 Implementar Banco de Dados | 17 | 1 | 1.5 | Resp. BD | - | 100%
3.2 Implementação – API | 18 | 6 | | | - | 100%
3.2.1 Criar base da API | 18 | 1 | | Resp. API | - | 100%
3.2.2 Criar rotas HTTP | 18 | 1 | | Resp. API | - | 100%
3.2.3 Desenvolver funções de conexão com o BD | 19 | 3 | | Resp. API | - | 100%
3.2.4 Criar rotas WebSocket | 22 | 2 | | Resp. API | | 100%

### 3.3 Implementação – Web 23 14 -100%

3.3.1 Tela Inicial 23 2 -100%
3.3.1.1 Criar tela | 23 | 1 | 2.3.1.1 | Resp. Front-End Web | - | 100%
3.3.1.2 Adicionar informações | 24 | 1 | | Resp. Front-End Web | - | 100%
3.3.2 Galeria | 25 | 3 | | | - | 100%
3.3.2.1 Criar tela | 25 | 1 | 2.3.1.2 | Resp. Front-End Web | - | 100%
3.3.2.2 Implementar inserção automática de imagens | 26 | 2 | 3.1 | Resp. Back-End Web | - | 100%
3.3.3 Cadastro / Login | 28 | 3 | | | - | 100%
3.3.3.1 Criar tela | 28 | 1 | 2.3.1.3 | Resp. Front-End Web | - | 100%
3.3.3.2 Conectar com a API | 29 | 1 | 3.1 | Resp. Back-End Web | - | 100%
3.3.4 Chat | 31 | 6 | | | - | 100%
3.3.4.1 Criar tela | 31 | 1 | 2.3.1.4 | Resp. Front-End Web | - | 100%
3.3.4.2 Conectar à API | 33 | 4 | | Resp. Back-End Web | - | 100%

DURAÇÃO
(Semanas)

Custos
Reais

%
CONCLUÍDA

ATIVIDADE | INÍCIO | Predecessoras | Recursos | PERÍODOS 1 2 3 4 5 6 7 8 9 10 11 12 13 14 15 16 17 18 19 20 21 22 23 24 25 26 27 28 29 30 31 32 33 34 35 36 37 38 39 40 41 42 43 44 45 46 47 48 49 50 51 52

DURAÇÃO
(Semanas)

Custos
Reais

%
CONCLUÍDA
3.4 Implementação – Mobile | 24 | 11 | | | - | 0%
3.4.1 Criar interface | 24 | 1 | 2.3.3.1 | Resp. Front-End Mobile | - | 0%
3.4.2 Implementar conexão Bluetooth com a prótese | 25 | 10 | | Resp. Back-End Mobile | - | 0%

### 3.5 Implementação – Desktop 24 19 -100%

3.5.1 Login / Cadastro 24 3 -100%
3.5.3.1 Criar tela | 24 | 1 | 2.3.2.3 | Resp. Front-End Desktop | - | 100%
3.5.3.2 Conectar com a API | 25 | 2 | 3.1 | Resp. Back-End Desktop | - | 100%
3.5.2 Gerenciamento de Fornecedores | 27 | 5 | | | - | 100%
3.5.2.1 Criar a tela de gerenciamento de fornecedores | 27 | 1 | 2.3.2.1 | Resp. Front-End Desktop | - | 100%
3.5.2.2 Implementar lógica | 28 | 2 | | Resp. Back-End Desktop | - | 100%
3.5.2.3 Conectar sistema à API | 30 | 2 | 3.1 | Resp. Back-End Desktop | - | 100%
3.5.3 Chat | 32 | 3 | | | - | 100%
3.5.3.1 Criar tela | 32 | 1 | 2.3.2.4 | Resp. Front-End Desktop | - | 100%
3.5.3.2 Conectar à API | 33 | 2 | 3.1 | Resp. Back-End Desktop | - | 100%
3.5.4 Gerenciamento de Usuários | 35 | 8 | | | - | 100%
3.5.4.1 Criar tela | 35 | 1 | 2.3.2.5 | Resp. Front-End Desktop | - | 100%
3.5.4.2 Implementar funcionalidade de pesquisa | 36 | 2 | 3.4.4.2 | Resp. Back-End Desktop | - | 100%
3.5.4.3 Implementar funcionalidades de adicionar, excluir e alterar dados | 38 | 5 | 3.4.4.2 | Resp. Back-End Desktop | - | 100%
3.6 Implementação – Engenharia | 16 | 37 | | | 210 | 0%
3.6.1 Comprar componentes eletrônicos | 16 | 3 | 2.2.4 | Grupo | 210,00 | 50%
3.6.2 Escrever Software para os eletrônicos | 19 | 6 | 3.5.1 | Resp. Firmware | | 100%
3.6.2 Comprar peças de montagem | 18 | 3 | 2.1.3 | Grupo | ??
3.6.3 Corrigir design 17 27 -0% Resp. Eng. Mecânica, impressora 3d
3.6.3.1 Imprimir protótipo | 17 | 2 | 2.1 | | - | 0%
3.6.3.2 Montar circuito | 19 | 1 | 2.2 | | - | 0%
3.6.3.3 Testar funcionamento | 20 | 2 | 3.5.3.1; 3.5.3.2 | Grupo | - | 0%
3.6.3.4 Identificar e corrigir falhas | 22 | 4 | 3.5.3.3 | | - | 0%
3.6.3.5 Repetir 3.5.3 | 17 | 27 | | | - | 0%

### 4. Finalização 44 9 -0%

4.1 Inspeção Final 44 6 -0%
4.1.1 Conferir se o sistema está de acordo com o projetado | 44 | 1 | 1,2,3 | Grupo | - | 0%
4.1.2 Verificação de segurança e integridade do sistema (testes) | 45 | 2 | 2,3 | Grupo | - | 0%
4.1.3 Validação final do sistema | 47 | 1 | 2, 3 | Cliente | - | 0%
4.1.4 Adicionar informações adicionais à documentação | 48 | 2 | 1
4.2 Conclusão do Projeto | 50 | 2 | | | - | 33%
4.2.1 Hospedar Site e API | 50 | 2 | '2, 3, 4.1 | Grupo | - | 100%
4.2.2 Cadastro dos administradores | 50 | 1 | 3 | Resp. BD | - | 0%
4.2.3 Arquivar os documentos do projeto | 50 | 1 | 2, 3, 4.1 | Grupo | - | 100%
4.2.3 Escrever instruções | 50 | 2 | 1, 2, 3, 4.1 | Resp. Documentação | | 0%
4.2.4 Liberar aplicação mobile para Download | 50 | 2 | 2,3 | Grupo | - | 0%
4.2.5 Apresentação do projeto para a comissão avaliativa de professores | 52 | 1 | 1, 2, 3, 4.1 | Grupo | - | 0%

Resp. Eng. Eletrônica,
componentes

Resp. Eng. Eletrônica,
Eng. Mecânica e
Firmware

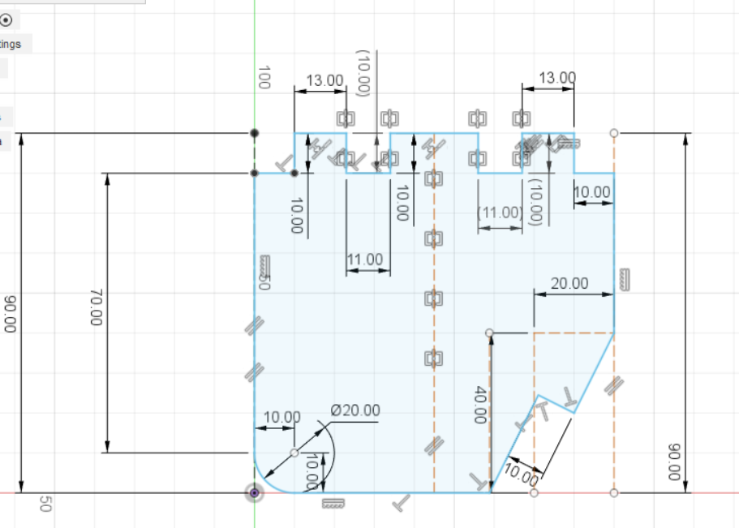
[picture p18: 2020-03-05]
Eng/imgs/sketchPalma.png

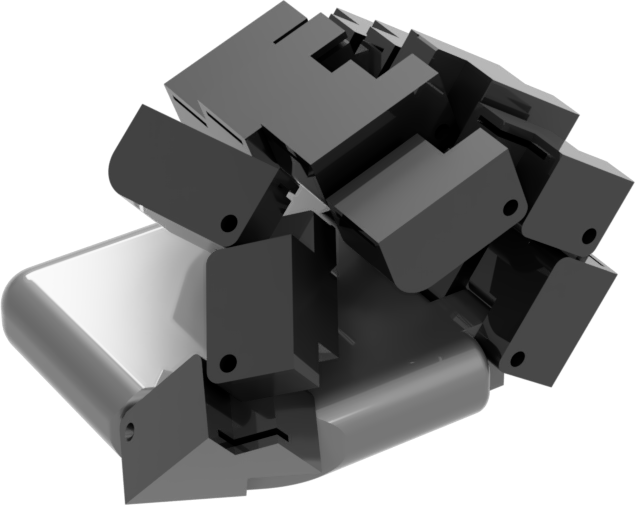
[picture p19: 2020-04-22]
Eng/imgs/tccRenderCortado4.png

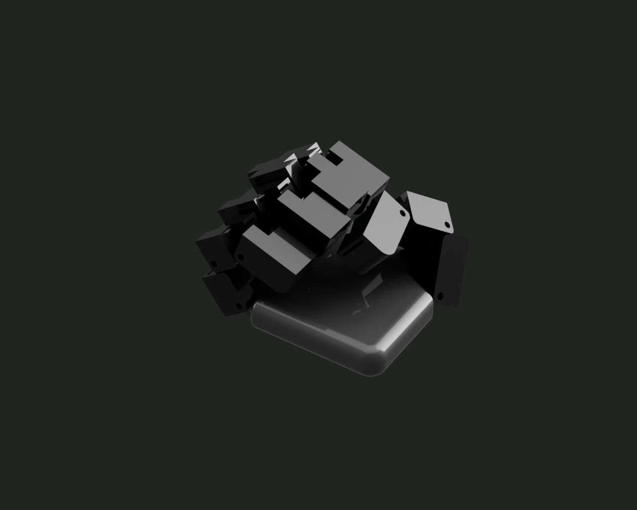
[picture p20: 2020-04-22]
Eng/imgs/tccRender.png

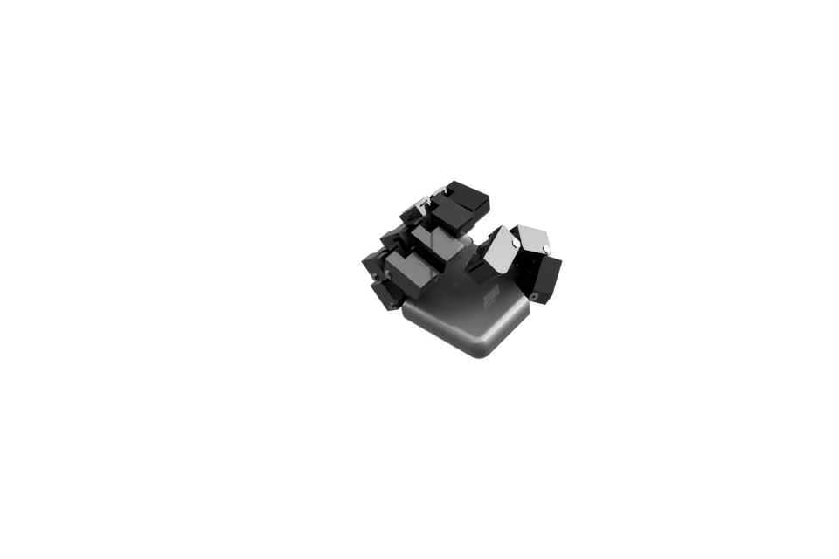
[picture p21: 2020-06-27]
Eng/imgs/Render2020-06-26-2.jpg

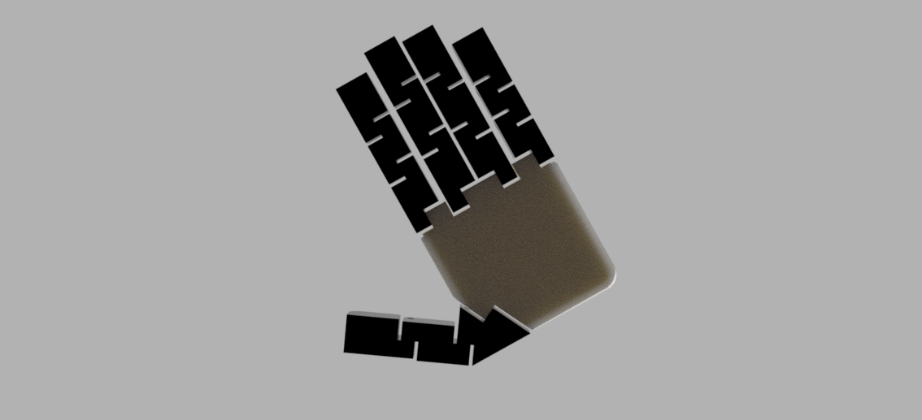
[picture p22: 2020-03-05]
Eng/imgs/P´rteseAbertaCima.png

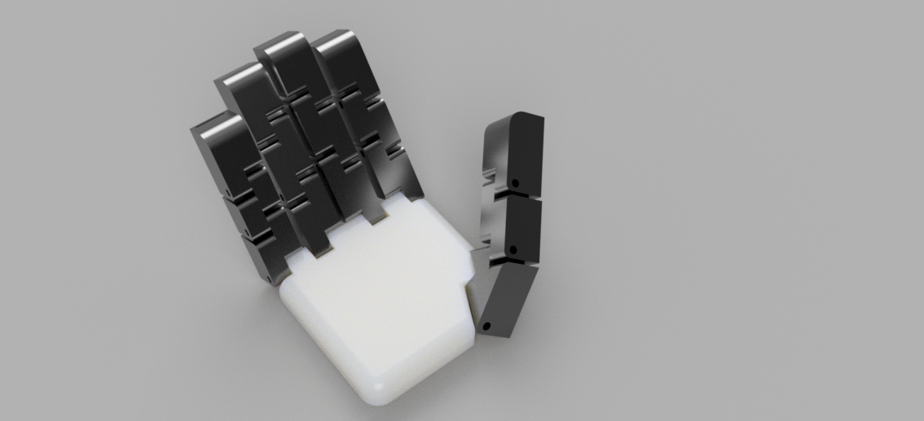
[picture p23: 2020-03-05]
Eng/imgs/PróteseMeioAberta.png

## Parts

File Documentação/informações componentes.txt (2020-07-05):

Placas baseadas no ATmega328P:
7 analog 
14 digital
Placas:
Uno;
Nano;
Pro Mini 5v;
power: uso: 5v, in: 7-12V, cons: 19mA
5v * 19mA = 95mW

nRF24 (RC):
1 voltage (3.3)
1 gnd
5 signal ( 1 clock, 2 serial, 2 state )
power: uso: 1.9-3.3v, in: 1.9-3.6v, cons: 12mA
3.3v * 12mA = 39.6mW transferencia 

hc05 (Bluetooth master/slave):
1 key (enable/disable)
1 voltage (5)
3 signal (3.3v) ( 2 serial, 1 state )

hc06 (Bluetooth slave):
1 key (enable/disable)
1 voltage (5)
3 signal (3.3v) ( 2 serial, 1 state )
power: uso: 5v power 3.3v serial, in: 3.6-6v, cons: 0.5mA standBy 8.5mA active
5v * 8.5mA = 42.5mW transferencia

total: 177.1mW

Buck Mini 360:
84 - 90% eficiência
Só vai ser usado para mandar carga para a bateria

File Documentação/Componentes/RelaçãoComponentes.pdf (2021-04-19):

Planilha1

### 10 Servos + Bateria 2200

Quantidade | Nome | Valor | Fornecedor | Adquirido
1 10 1 1 1 1 | ESP32s Servo Mg90s Carregador Bateria Litio 2s Lipo 7a C/ Proteção Carga Bms Buck Converter Carregador Li-Po Li-po 7,4V 2200mA | R$ 40,00 R$ 25,20 R$ 15,99 R$ 10,90 R$ 59,90 R$ 169,00 | Curto Circuito (https://www.curtocircuito.com.br/servo-motor-mg90s.html) Mercado Livre (https://produto.mercadolivre.com.br/MLB-1681140399-2-carregador-bateria-litio-2s-lipo-7a-c-proteco-carga-bms-_JM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) Curto Circuito (https://www.curtocircuito.com.br/conversor-dc-dc-step-down-lm2596.html) Mercado Livre (https://produto.mercadolivre.com.br/MLB-817957196-carregador-imax-b3-pbateria-lipo-2s-e-3s-_JM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) Mercado Livre (https://produto.mercadolivre.com.br/MLB-1726002728-bateria-lipo-74v-2s-2200mah-30c-_JM?matt_tool=18956390)
Total: | R$ 507,79

### 8 Servos + Bateria 2200

Quantidade | Nome | Valor | Fornecedor | Adquirido
1 8 1 1 1 1 | ESP32s Servo Mg90s Carregador Bateria Litio 2s Lipo 7a C/ Proteção Carga Bms Buck Converter Carregador Li-Po Li-po 7,4V 2200mA | R$ 40,00 R$ 25,20 R$ 15,99 R$ 10,90 R$ 59,90 R$ 169,00 | Curto Circuito (https://www.curtocircuito.com.br/servo-motor-mg90s.html) Mercado Livre (https://produto.mercadolivre.com.br/MLB-1681140399-2-carregador-bateria-litio-2s-lipo-7a-c-proteco-carga-bms-_JM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) Curto Circuito (https://www.curtocircuito.com.br/conversor-dc-dc-step-down-lm2596.html) Mercado Livre (https://produto.mercadolivre.com.br/MLB-817957196-carregador-imax-b3-pbateria-lipo-2s-e-3s-_JM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) Mercado Livre (https://produto.mercadolivre.com.br/MLB-1726002728-bateria-lipo-74v-2s-2200mah-30c-_JM?matt_tool=18956390)
Total: | R$ 457,39

### 6 Servos + Bateria 2200

Quantidade | Nome | Valor | Fornecedor | Adquirido
1 6 1 1 1 1 | ESP32s Servo Mg90s Carregador Bateria Litio 2s Lipo 7a C/ Proteção Carga Bms Buck Converter Carregador Li-Po Li-po 7,4V 2200mA | R$ 40,00 R$ 25,20 R$ 15,99 R$ 10,90 R$ 59,90 R$ 169,00 | Curto Circuito (https://www.curtocircuito.com.br/servo-motor-mg90s.html) Mercado Livre (https://produto.mercadolivre.com.br/MLB-1681140399-2-carregador-bateria-litio-2s-lipo-7a-c-proteco-carga-bms-_JM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) Curto Circuito (https://www.curtocircuito.com.br/conversor-dc-dc-step-down-lm2596.html) Mercado Livre (https://produto.mercadolivre.com.br/MLB-817957196-carregador-imax-b3-pbateria-lipo-2s-e-3s-_JM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) Mercado Livre (https://produto.mercadolivre.com.br/MLB-1726002728-bateria-lipo-74v-2s-2200mah-30c-_JM?matt_tool=18956390)
Total: | R$ 406,99

### 5 Servos + Bateria 2200

Quantidade | Nome | Valor | Fornecedor | Adquirido
1 5 1 1 1 1 | ESP32s Servo Mg90s Carregador Bateria Litio 2s Lipo 7a C/ Proteção Carga Bms Buck Converter Carregador Li-Po Li-po 7,4V 2200mA | R$ 40,00 R$ 25,20 R$ 15,99 R$ 10,90 R$ 59,90 R$ 169,00 | Curto Circuito (https://www.curtocircuito.com.br/servo-motor-mg90s.html) Mercado Livre (https://produto.mercadolivre.com.br/MLB-1681140399-2-carregador-bateria-litio-2s-lipo-7a-c-proteco-carga-bms-_JM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) Curto Circuito (https://www.curtocircuito.com.br/conversor-dc-dc-step-down-lm2596.html) Mercado Livre (https://produto.mercadolivre.com.br/MLB-817957196-carregador-imax-b3-pbateria-lipo-2s-e-3s-_JM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) Mercado Livre (https://produto.mercadolivre.com.br/MLB-1726002728-bateria-lipo-74v-2s-2200mah-30c-_JM?matt_tool=18956390)
Total: | R$ 381,79

### 10 Servos + Bateria 500

Quantidade | Nome | Valor | Fornecedor | Adquirido
1 10 1 1 1 1 | ESP32s Servo Mg90s Carregador Bateria Litio 2s Lipo 7a C/ Proteção Carga Bms Buck Converter Carregador Li-Po Li-po 7,4V 500mA | R$ 40,00 R$ 25,20 R$ 15,99 R$ 10,90 R$ 59,90 R$ 100,00 | Curto Circuito (https://www.curtocircuito.com.br/servo-motor-mg90s.html) Mercado Livre (https://produto.mercadolivre.com.br/MLB-1681140399-2-carregador-bateria-litio-2s-lipo-7a-c-proteco-carga-bms-_JM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) Curto Circuito (https://www.curtocircuito.com.br/conversor-dc-dc-step-down-lm2596.html) Mercado Livre (https://produto.mercadolivre.com.br/MLB-817957196-carregador-imax-b3-pbateria-lipo-2s-e-3s-_JM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) Mercado Livre (https://produto.mercadolivre.com.br/MLB-889357237-bateria-lipo-500mah-2s-74v-20c-turnigy-_JM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)
Total: | R$ 438,79

### 8 Servos + Bateria 500

Quantidade | Nome | Valor | Fornecedor | Adquirido
1 8 1 1 1 1 | ESP32s Servo Mg90s Carregador Bateria Litio 2s Lipo 7a C/ Proteção Carga Bms Buck Converter Carregador Li-Po Li-po 7,4V 500mA | R$ 40,00 R$ 25,20 R$ 15,99 R$ 10,90 R$ 59,90 R$ 100,00 | Curto Circuito (https://www.curtocircuito.com.br/servo-motor-mg90s.html) Mercado Livre (https://produto.mercadolivre.com.br/MLB-1681140399-2-carregador-bateria-litio-2s-lipo-7a-c-proteco-carga-bms-_JM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) Curto Circuito (https://www.curtocircuito.com.br/conversor-dc-dc-step-down-lm2596.html) Mercado Livre (https://produto.mercadolivre.com.br/MLB-817957196-carregador-imax-b3-pbateria-lipo-2s-e-3s-_JM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) Mercado Livre (https://produto.mercadolivre.com.br/MLB-889357237-bateria-lipo-500mah-2s-74v-20c-turnigy-_JM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)
Total: | R$ 388,39

### 6 Servos + Bateria 500

Quantidade | Nome | Valor | Fornecedor | Adquirido
1 6 1 1 1 1 | ESP32s Servo Mg90s Carregador Bateria Litio 2s Lipo 7a C/ Proteção Carga Bms Buck Converter Carregador Li-Po Li-po 7,4V 500mA | R$ 40,00 R$ 25,20 R$ 15,99 R$ 10,90 R$ 59,90 R$ 100,00 | Curto Circuito (https://www.curtocircuito.com.br/servo-motor-mg90s.html) Mercado Livre (https://produto.mercadolivre.com.br/MLB-1681140399-2-carregador-bateria-litio-2s-lipo-7a-c-proteco-carga-bms-_JM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) Curto Circuito (https://www.curtocircuito.com.br/conversor-dc-dc-step-down-lm2596.html) Mercado Livre (https://produto.mercadolivre.com.br/MLB-817957196-carregador-imax-b3-pbateria-lipo-2s-e-3s-_JM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) Mercado Livre (https://produto.mercadolivre.com.br/MLB-889357237-bateria-lipo-500mah-2s-74v-20c-turnigy-_JM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)
Total: | R$ 337,99

### 5 Servos + Bateria 500

Quantidade | Nome | Valor | Fornecedor | Adquirido
1 5 1 1 1 1 | ESP32s Servo Mg90s Carregador Bateria Litio 2s Lipo 7a C/ Proteção Carga Bms Buck Converter Carregador Li-Po Li-po 7,4V 500mA | R$ 40,00 R$ 25,20 R$ 15,99 R$ 10,90 R$ 59,90 R$ 100,00 | Curto Circuito (https://www.curtocircuito.com.br/servo-motor-mg90s.html) Mercado Livre (https://produto.mercadolivre.com.br/MLB-1681140399-2-carregador-bateria-litio-2s-lipo-7a-c-proteco-carga-bms-_JM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) Curto Circuito (https://www.curtocircuito.com.br/conversor-dc-dc-step-down-lm2596.html) Mercado Livre (https://produto.mercadolivre.com.br/MLB-817957196-carregador-imax-b3-pbateria-lipo-2s-e-3s-_JM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) Mercado Livre (https://produto.mercadolivre.com.br/MLB-889357237-bateria-lipo-500mah-2s-74v-20c-turnigy-_JM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)
Total: | R$ 312,79

### 10 Servos + Sem Bateria

Quantidade | Nome | Valor | Fornecedor | Adquirido
1 10 1 1 | ESP32s Servo Mg90s Carregador Bateria Litio 2s Lipo 7a C/ Proteção Carga Bms Buck Converter | R$ 40,00 R$ 25,20 R$ 15,99 R$ 10,90 | Curto Circuito (https://www.curtocircuito.com.br/servo-motor-mg90s.html) Mercado Livre (https://produto.mercadolivre.com.br/MLB-1681140399-2-carregador-bateria-litio-2s-lipo-7a-c-proteco-carga-bms-_JM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) Curto Circuito (https://www.curtocircuito.com.br/conversor-dc-dc-step-down-lm2596.html)
Total: | R$ 278,89

### 8 Servos + Sem Bateria

Quantidade | Nome | Valor | Fornecedor | Adquirido
1 8 1 1 | ESP32s Servo Mg90s Carregador Bateria Litio 2s Lipo 7a C/ Proteção Carga Bms Buck Converter | R$ 40,00 R$ 25,20 R$ 15,99 R$ 10,90 | Curto Circuito (https://www.curtocircuito.com.br/servo-motor-mg90s.html) Mercado Livre (https://produto.mercadolivre.com.br/MLB-1681140399-2-carregador-bateria-litio-2s-lipo-7a-c-proteco-carga-bms-_JM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) Curto Circuito (https://www.curtocircuito.com.br/conversor-dc-dc-step-down-lm2596.html)
Total: | R$ 228,49

### 6 Servos + Sem Bateria

Quantidade | Nome | Valor | Fornecedor | Adquirido
1 6 1 1 | ESP32s Servo Mg90s Carregador Bateria Litio 2s Lipo 7a C/ Proteção Carga Bms Buck Converter | R$ 40,00 R$ 25,20 R$ 15,99 R$ 10,90 | Curto Circuito (https://www.curtocircuito.com.br/servo-motor-mg90s.html) Mercado Livre (https://produto.mercadolivre.com.br/MLB-1681140399-2-carregador-bateria-litio-2s-lipo-7a-c-proteco-carga-bms-_JM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) Curto Circuito (https://www.curtocircuito.com.br/conversor-dc-dc-step-down-lm2596.html)
Total: | R$ 178,09

### 5 Servos + Sem Bateria

Quantidade | Nome | Valor | Fornecedor | Adquirido
1 5 1 1 | ESP32s Servo Mg90s Carregador Bateria Litio 2s Lipo 7a C/ Proteção Carga Bms Buck Converter | R$ 40,00 R$ 25,20 R$ 15,99 R$ 10,90 | Curto Circuito (https://www.curtocircuito.com.br/servo-motor-mg90s.html) Mercado Livre (https://produto.mercadolivre.com.br/MLB-1681140399-2-carregador-bateria-litio-2s-lipo-7a-c-proteco-carga-bms-_JM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) Curto Circuito (https://www.curtocircuito.com.br/conversor-dc-dc-step-down-lm2596.html)
Total: | R$ 152,89

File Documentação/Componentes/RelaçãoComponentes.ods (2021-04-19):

10 Servos + Bateria 2200 |  |  |  |  | 10 Servos + Bateria 500 |  |  |  |  | 10 Servos + Sem Bateria
Quantidade | Nome | Valor | Fornecedor | Adquirido | Quantidade | Nome | Valor | Fornecedor | Adquirido | Quantidade | Nome | Valor | Fornecedor | Adquirido
1 | ESP32s | R$ 40,00 |  |  | 1 | ESP32s | R$ 40,00 |  |  | 1 | ESP32s | R$ 40,00
10 | Servo Mg90s | R$ 25,20 | Curto Circuito (https://www.curtocircuito.com.br/servo-motor-mg90s.html) |  | 10 | Servo Mg90s | R$ 25,20 | Curto Circuito (https://www.curtocircuito.com.br/servo-motor-mg90s.html) |  | 10 | Servo Mg90s | R$ 25,20 | Curto Circuito (https://www.curtocircuito.com.br/servo-motor-mg90s.html)
1 | Carregador Bateria Litio 2s Lipo 7a C/ Proteção Carga Bms | R$ 15,99 | Mercado Livre (https://produto.mercadolivre.com.br/MLB-1681140399-2-carregador-bateria-litio-2s-lipo-7a-c-proteco-carga-bms-_JM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) |  | 1 | Carregador Bateria Litio 2s Lipo 7a C/ Proteção Carga Bms | R$ 15,99 | Mercado Livre (https://produto.mercadolivre.com.br/MLB-1681140399-2-carregador-bateria-litio-2s-lipo-7a-c-proteco-carga-bms-_JM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) |  | 1 | Carregador Bateria Litio 2s Lipo 7a C/ Proteção Carga Bms | R$ 15,99 | Mercado Livre (https://produto.mercadolivre.com.br/MLB-1681140399-2-carregador-bateria-litio-2s-lipo-7a-c-proteco-carga-bms-_JM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)
1 | Buck Converter | R$ 10,90 | Curto Circuito (https://www.curtocircuito.com.br/conversor-dc-dc-step-down-lm2596.html) |  | 1 | Buck Converter | R$ 10,90 | Curto Circuito (https://www.curtocircuito.com.br/conversor-dc-dc-step-down-lm2596.html) |  | 1 | Buck Converter | R$ 10,90 | Curto Circuito (https://www.curtocircuito.com.br/conversor-dc-dc-step-down-lm2596.html)
1 | Carregador Li-Po | R$ 59,90 | Mercado Livre (https://produto.mercadolivre.com.br/MLB-817957196-carregador-imax-b3-pbateria-lipo-2s-e-3s-_JM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) |  | 1 | Carregador Li-Po | R$ 59,90 | Mercado Livre (https://produto.mercadolivre.com.br/MLB-817957196-carregador-imax-b3-pbateria-lipo-2s-e-3s-_JM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) |  | Total: | R$ 278,89
1 | Li-po 7,4V 2200mA | R$ 169,00 | Mercado Livre (https://produto.mercadolivre.com.br/MLB-1726002728-bateria-lipo-74v-2s-2200mah-30c-_JM?matt_tool=18956390) |  | 1 | Li-po 7,4V 500mA | R$ 100,00 | Mercado Livre (https://produto.mercadolivre.com.br/MLB-889357237-bateria-lipo-500mah-2s-74v-20c-turnigy-_JM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)
Total: | R$ 507,79 |  |  |  | Total: | R$ 438,79
8 Servos + Bateria 2200 |  |  |  |  | 8 Servos + Bateria 500 |  |  |  |  | 8 Servos + Sem Bateria
Quantidade | Nome | Valor | Fornecedor | Adquirido | Quantidade | Nome | Valor | Fornecedor | Adquirido | Quantidade | Nome | Valor | Fornecedor | Adquirido
1 | ESP32s | R$ 40,00 |  |  | 1 | ESP32s | R$ 40,00 |  |  | 1 | ESP32s | R$ 40,00
8 | Servo Mg90s | R$ 25,20 | Curto Circuito (https://www.curtocircuito.com.br/servo-motor-mg90s.html) |  | 8 | Servo Mg90s | R$ 25,20 | Curto Circuito (https://www.curtocircuito.com.br/servo-motor-mg90s.html) |  | 8 | Servo Mg90s | R$ 25,20 | Curto Circuito (https://www.curtocircuito.com.br/servo-motor-mg90s.html)
1 | Carregador Bateria Litio 2s Lipo 7a C/ Proteção Carga Bms | R$ 15,99 | Mercado Livre (https://produto.mercadolivre.com.br/MLB-1681140399-2-carregador-bateria-litio-2s-lipo-7a-c-proteco-carga-bms-_JM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) |  | 1 | Carregador Bateria Litio 2s Lipo 7a C/ Proteção Carga Bms | R$ 15,99 | Mercado Livre (https://produto.mercadolivre.com.br/MLB-1681140399-2-carregador-bateria-litio-2s-lipo-7a-c-proteco-carga-bms-_JM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) |  | 1 | Carregador Bateria Litio 2s Lipo 7a C/ Proteção Carga Bms | R$ 15,99 | Mercado Livre (https://produto.mercadolivre.com.br/MLB-1681140399-2-carregador-bateria-litio-2s-lipo-7a-c-proteco-carga-bms-_JM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)
1 | Buck Converter | R$ 10,90 | Curto Circuito (https://www.curtocircuito.com.br/conversor-dc-dc-step-down-lm2596.html) |  | 1 | Buck Converter | R$ 10,90 | Curto Circuito (https://www.curtocircuito.com.br/conversor-dc-dc-step-down-lm2596.html) |  | 1 | Buck Converter | R$ 10,90 | Curto Circuito (https://www.curtocircuito.com.br/conversor-dc-dc-step-down-lm2596.html)
1 | Carregador Li-Po | R$ 59,90 | Mercado Livre (https://produto.mercadolivre.com.br/MLB-817957196-carregador-imax-b3-pbateria-lipo-2s-e-3s-_JM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) |  | 1 | Carregador Li-Po | R$ 59,90 | Mercado Livre (https://produto.mercadolivre.com.br/MLB-817957196-carregador-imax-b3-pbateria-lipo-2s-e-3s-_JM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) |  | Total: | R$ 228,49
1 | Li-po 7,4V 2200mA | R$ 169,00 | Mercado Livre (https://produto.mercadolivre.com.br/MLB-1726002728-bateria-lipo-74v-2s-2200mah-30c-_JM?matt_tool=18956390) |  | 1 | Li-po 7,4V 500mA | R$ 100,00 | Mercado Livre (https://produto.mercadolivre.com.br/MLB-889357237-bateria-lipo-500mah-2s-74v-20c-turnigy-_JM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)
Total: | R$ 457,39 |  |  |  | Total: | R$ 388,39
6 Servos + Bateria 2200 |  |  |  |  | 6 Servos + Bateria 500 |  |  |  |  | 6 Servos + Sem Bateria
Quantidade | Nome | Valor | Fornecedor | Adquirido | Quantidade | Nome | Valor | Fornecedor | Adquirido | Quantidade | Nome | Valor | Fornecedor | Adquirido
1 | ESP32s | R$ 40,00 |  |  | 1 | ESP32s | R$ 40,00 |  |  | 1 | ESP32s | R$ 40,00
6 | Servo Mg90s | R$ 25,20 | Curto Circuito (https://www.curtocircuito.com.br/servo-motor-mg90s.html) |  | 6 | Servo Mg90s | R$ 25,20 | Curto Circuito (https://www.curtocircuito.com.br/servo-motor-mg90s.html) |  | 6 | Servo Mg90s | R$ 25,20 | Curto Circuito (https://www.curtocircuito.com.br/servo-motor-mg90s.html)
1 | Carregador Bateria Litio 2s Lipo 7a C/ Proteção Carga Bms | R$ 15,99 | Mercado Livre (https://produto.mercadolivre.com.br/MLB-1681140399-2-carregador-bateria-litio-2s-lipo-7a-c-proteco-carga-bms-_JM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) |  | 1 | Carregador Bateria Litio 2s Lipo 7a C/ Proteção Carga Bms | R$ 15,99 | Mercado Livre (https://produto.mercadolivre.com.br/MLB-1681140399-2-carregador-bateria-litio-2s-lipo-7a-c-proteco-carga-bms-_JM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) |  | 1 | Carregador Bateria Litio 2s Lipo 7a C/ Proteção Carga Bms | R$ 15,99 | Mercado Livre (https://produto.mercadolivre.com.br/MLB-1681140399-2-carregador-bateria-litio-2s-lipo-7a-c-proteco-carga-bms-_JM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)
1 | Buck Converter | R$ 10,90 | Curto Circuito (https://www.curtocircuito.com.br/conversor-dc-dc-step-down-lm2596.html) |  | 1 | Buck Converter | R$ 10,90 | Curto Circuito (https://www.curtocircuito.com.br/conversor-dc-dc-step-down-lm2596.html) |  | 1 | Buck Converter | R$ 10,90 | Curto Circuito (https://www.curtocircuito.com.br/conversor-dc-dc-step-down-lm2596.html)
1 | Carregador Li-Po | R$ 59,90 | Mercado Livre (https://produto.mercadolivre.com.br/MLB-817957196-carregador-imax-b3-pbateria-lipo-2s-e-3s-_JM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) |  | 1 | Carregador Li-Po | R$ 59,90 | Mercado Livre (https://produto.mercadolivre.com.br/MLB-817957196-carregador-imax-b3-pbateria-lipo-2s-e-3s-_JM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) |  | Total: | R$ 178,09
1 | Li-po 7,4V 2200mA | R$ 169,00 | Mercado Livre (https://produto.mercadolivre.com.br/MLB-1726002728-bateria-lipo-74v-2s-2200mah-30c-_JM?matt_tool=18956390) |  | 1 | Li-po 7,4V 500mA | R$ 100,00 | Mercado Livre (https://produto.mercadolivre.com.br/MLB-889357237-bateria-lipo-500mah-2s-74v-20c-turnigy-_JM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)
Total: | R$ 406,99 |  |  |  | Total: | R$ 337,99
5 Servos + Bateria 2200 |  |  |  |  | 5 Servos + Bateria 500 |  |  |  |  | 5 Servos + Sem Bateria
Quantidade | Nome | Valor | Fornecedor | Adquirido | Quantidade | Nome | Valor | Fornecedor | Adquirido | Quantidade | Nome | Valor | Fornecedor | Adquirido
1 | ESP32s | R$ 40,00 |  |  | 1 | ESP32s | R$ 40,00 |  |  | 1 | ESP32s | R$ 40,00
5 | Servo Mg90s | R$ 25,20 | Curto Circuito (https://www.curtocircuito.com.br/servo-motor-mg90s.html) |  | 5 | Servo Mg90s | R$ 25,20 | Curto Circuito (https://www.curtocircuito.com.br/servo-motor-mg90s.html) |  | 5 | Servo Mg90s | R$ 25,20 | Curto Circuito (https://www.curtocircuito.com.br/servo-motor-mg90s.html)
1 | Carregador Bateria Litio 2s Lipo 7a C/ Proteção Carga Bms | R$ 15,99 | Mercado Livre (https://produto.mercadolivre.com.br/MLB-1681140399-2-carregador-bateria-litio-2s-lipo-7a-c-proteco-carga-bms-_JM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) |  | 1 | Carregador Bateria Litio 2s Lipo 7a C/ Proteção Carga Bms | R$ 15,99 | Mercado Livre (https://produto.mercadolivre.com.br/MLB-1681140399-2-carregador-bateria-litio-2s-lipo-7a-c-proteco-carga-bms-_JM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) |  | 1 | Carregador Bateria Litio 2s Lipo 7a C/ Proteção Carga Bms | R$ 15,99 | Mercado Livre (https://produto.mercadolivre.com.br/MLB-1681140399-2-carregador-bateria-litio-2s-lipo-7a-c-proteco-carga-bms-_JM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)
1 | Buck Converter | R$ 10,90 | Curto Circuito (https://www.curtocircuito.com.br/conversor-dc-dc-step-down-lm2596.html) |  | 1 | Buck Converter | R$ 10,90 | Curto Circuito (https://www.curtocircuito.com.br/conversor-dc-dc-step-down-lm2596.html) |  | 1 | Buck Converter | R$ 10,90 | Curto Circuito (https://www.curtocircuito.com.br/conversor-dc-dc-step-down-lm2596.html)
1 | Carregador Li-Po | R$ 59,90 | Mercado Livre (https://produto.mercadolivre.com.br/MLB-817957196-carregador-imax-b3-pbateria-lipo-2s-e-3s-_JM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) |  | 1 | Carregador Li-Po | R$ 59,90 | Mercado Livre (https://produto.mercadolivre.com.br/MLB-817957196-carregador-imax-b3-pbateria-lipo-2s-e-3s-_JM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) |  | Total: | R$ 152,89
1 | Li-po 7,4V 2200mA | R$ 169,00 | Mercado Livre (https://produto.mercadolivre.com.br/MLB-1726002728-bateria-lipo-74v-2s-2200mah-30c-_JM?matt_tool=18956390) |  | 1 | Li-po 7,4V 500mA | R$ 100,00 | Mercado Livre (https://produto.mercadolivre.com.br/MLB-889357237-bateria-lipo-500mah-2s-74v-20c-turnigy-_JM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)
Total: | R$ 381,79 |  |  |  | Total: | R$ 312,79

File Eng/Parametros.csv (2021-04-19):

ProximalDiametroPolia | mm | 20 mm
Proximal1Comprimento | mm | 45 mm
ProximalExpessura | mm | 20 mm
ProximalBarrigaExpessura | mm | 15 mm
ProximalOffsetBarriga | mm | ( ProximalExpessura - ProximalBarrigaExpessura ) / 2
ProximalLargura | mm | 8 mm
ProximalDiametroBuracoPolia | mm | 3 mm
ProximalPoliaBuracoAltura | mm | ProximalExpessura / 2 - 1 mm
ProximalDiametroEncaixeMedio | mm | 15 mm
EixoDiametro | mm | 4.2 mm
EixoFillet | mm | 0.2 mm
FilletExternoPolia | mm | 0.2 mm
FilletExternoCorpo | mm | 2 mm
BuracoPrenderFio | mm | 1.2 mm
d38 | mm | ProximalDiametroPolia
d58 | mm | EixoDiametro
d70 | mm | ProximalDiametroEncaixeMedio
d71 | mm | EixoDiametro
d72 | mm | Proximal1Comprimento - ProximalDiametroPolia / 2 - ProximalDiametroEncaixeMedio / 2
d73 | mm | ProximalBarrigaExpessura
d74 | mm | ProximalOffsetBarriga
d75 | mm | ProximalOffsetBarriga
d46 | mm | ProximalLargura
d47 | deg | 0.0 deg
d48 | mm | ProximalDiametroBuracoPolia
d49 | mm | ProximalPoliaBuracoAltura
d50 | mm | 100 mm
d51 | mm | ProximalLargura / 2
d81 | mm | BuracoPrenderFio
d82 | mm | ProximalDiametroPolia / 2 - BuracoPrenderFio / 2 - 0.5 mm
d52 | deg | 360.0 deg
d62 |  | 1
d63 | mm | EixoFillet
d76 |  | 1
d77 | mm | FilletExternoPolia
d78 |  | 1
d79 | mm | FilletExternoCorpo
d83 | mm | -ProximalLargura
d84 | deg | 0.0 deg
MediaDiametroPolia | mm | ProximalDiametroPolia
MediaDiametroEncaixeDistal | mm | ProximalDiametroEncaixeMedio
Media1Comprimento | mm | 35 mm
MediaLargura | mm | 20 mm
MediaPoliaBuracoAltura | mm | ProximalPoliaBuracoAltura
MediaPoliaBuracoDiametro | mm | 3 mm
DistalDiametroPolia | mm | 15 mm
Distal1Tamanho | mm | 30 mm
DistalPoliaBuracoAltura | mm | DistalDiametroPolia / 2 - 1 mm
d123 | mm | DistalDiametroPolia
d126 | mm | Distal1Tamanho - DistalDiametroPolia / 2
d127 | mm | ProximalLargura
d128 | deg | 0.0 deg
d129 | mm | ProximalDiametroBuracoPolia
d130 | mm | ProximalLargura / 2
d131 | mm | DistalPoliaBuracoAltura
d133 | deg | 360.0 deg
d134 |  | 1
d135 | mm | FilletExternoCorpo
d136 |  | 1
d137 | mm | FilletExternoPolia
d138 |  | 1
d139 | mm | FilletExternoPolia
d140 | mm | EixoDiametro
d141 | mm | BuracoPrenderFio
d142 | mm | DistalDiametroPolia / 2 - 1 mm
d143 | mm | -ProximalExpessura
d144 | deg | 0.0 deg
d145 |  | 1
d146 | mm | EixoFillet
d43 | mm | MediaDiametroPolia
d44 | mm | MediaDiametroEncaixeDistal
d54 | mm | Media1Comprimento - MediaDiametroPolia / 2 - MediaDiametroEncaixeDistal / 2
d56 | mm | MediaLargura
d57 | deg | 0.0 deg
d60 | mm | MediaLargura / 2 - ProximalLargura / 2 - 0.5 mm
d61 | mm | MediaDiametroPolia + 0.5 mm
d66 | mm | MediaDiametroEncaixeDistal
d67 | mm | Media1Comprimento - MediaDiametroPolia / 2 - MediaDiametroEncaixeDistal / 2
d86 | mm | MediaPoliaBuracoDiametro
d87 | mm | ( ( MediaLargura / 2 - ProximalLargura / 2 - 0.5 mm ) / 2 mm ) * 1 mm
d88 | mm | MediaPoliaBuracoAltura
d89 | mm | MediaPoliaBuracoDiametro
d90 | mm | MediaLargura - ( MediaLargura / 2 - ProximalLargura / 2 - 0.5 mm ) / 2
d91 | mm | MediaPoliaBuracoAltura
d93 | mm | EixoDiametro
d96 | mm | EixoDiametro
d97 | mm | Media1Comprimento - MediaDiametroPolia / 2 - MediaDiametroEncaixeDistal / 2
d106 | mm | BuracoPrenderFio
d107 | mm | ProximalDiametroPolia / 2 - 1 mm
d64 | mm | ProximalLargura + 1 mm
d65 | deg | 0.0 deg
d68 | mm | ProximalLargura + 1 mm
d69 | deg | 0.0 deg
d92 | deg | 360.0 deg
d94 | mm | -MediaLargura
d95 | deg | 0.0 deg
d98 | mm | -MediaLargura
d99 | deg | 0.0 deg
d100 |  | 1
d101 | mm | EixoFillet
d102 |  | 1
d103 | mm | FilletExternoCorpo
d104 |  | 1
d105 | mm | FilletExternoPolia
d108 | mm | -MediaLargura
d109 | deg | 0.0 deg
d110 |  | 1
d111 | mm | FilletExternoPolia
d1 | mm | MediaDiametroPolia
Proximal2Comprimento | mm | 45 mm
ProximalDiametroPolia_1 | mm | 20 mm
Proximal1Comprimento_1 | mm | 35 mm
ProximalExpessura_1 | mm | 20 mm
ProximalBarrigaExpessura_1 | mm | 15 mm
ProximalOffsetBarriga_1 | mm | ( ProximalExpessura_1 - ProximalBarrigaExpessura_1 ) / 2
ProximalLargura_1 | mm | 8 mm
ProximalDiametroBuracoPolia_1 | mm | 3 mm
ProximalPoliaBuracoAltura_1 | mm | ProximalExpessura_1 / 2 - 1 mm
ProximalDiametroEncaixeMedio_1 | mm | 15 mm
EixoDiametro_1 | mm | 4.2 mm
EixoFillet_1 | mm | 0.2 mm
FilletExternoPolia_1 | mm | 0.2 mm
FilletExternoCorpo_1 | mm | 2 mm
BuracoPrenderFio_1 | mm | 1.2 mm
MediaDiametroPolia_1 | mm | ProximalDiametroPolia_1
MediaDiametroEncaixeDistal_1 | mm | ProximalDiametroEncaixeMedio_1
Media1Comprimento_1 | mm | 30 mm
MediaLargura_1 | mm | 20 mm
MediaPoliaBuracoAltura_1 | mm | ProximalPoliaBuracoAltura_1
MediaPoliaBuracoDiametro_1 | mm | 3 mm
DistalDiametroPolia_1 | mm | 15 mm
Distal1Tamanho_1 | mm | 30 mm
DistalPoliaBuracoAltura_1 | mm | DistalDiametroPolia_1 / 2 - 1 mm
d123_1 | mm | DistalDiametroPolia_1
d126_1 | mm | Distal1Tamanho_1 - DistalDiametroPolia_1 / 2
d127_1 | mm | ProximalLargura_1
d128_1 | deg | 0.0 deg
d129_1 | mm | ProximalDiametroBuracoPolia_1
d130_1 | mm | ProximalLargura_1 / 2
d131_1 | mm | DistalPoliaBuracoAltura_1
d133_1 | deg | 360.0 deg
d134_1 |  | 1
d135_1 | mm | FilletExternoCorpo_1
d136_1 |  | 1
d137_1 | mm | FilletExternoPolia_1
d138_1 |  | 1
d139_1 | mm | FilletExternoPolia_1
d140_1 | mm | EixoDiametro_1
d141_1 | mm | BuracoPrenderFio_1
d142_1 | mm | DistalDiametroPolia_1 / 2 - 1 mm
d143_1 | mm | -ProximalExpessura_1
d144_1 | deg | 0.0 deg
d145_1 |  | 1
d146_1 | mm | EixoFillet_1
d43_1 | mm | MediaDiametroPolia_1
d44_1 | mm | MediaDiametroEncaixeDistal_1
d54_1 | mm | Media1Comprimento_1 - MediaDiametroPolia_1 / 2 - MediaDiametroEncaixeDistal_1 / 2
d56_1 | mm | MediaLargura_1
d57_1 | deg | 0.0 deg
d60_1 | mm | MediaLargura_1 / 2 - ProximalLargura_1 / 2 - 0.5 mm
d61_1 | mm | MediaDiametroPolia_1 + 0.5 mm
d66_1 | mm | MediaDiametroEncaixeDistal_1
d67_1 | mm | Media1Comprimento_1 - MediaDiametroPolia_1 / 2 - MediaDiametroEncaixeDistal_1 / 2
d86_1 | mm | MediaPoliaBuracoDiametro_1
d87_1 | mm | ( ( MediaLargura_1 / 2 - ProximalLargura_1 / 2 - 0.5 mm ) / 2 mm ) * 1 mm
d88_1 | mm | MediaPoliaBuracoAltura_1
d89_1 | mm | MediaPoliaBuracoDiametro_1
d90_1 | mm | MediaLargura_1 - ( MediaLargura_1 / 2 - ProximalLargura_1 / 2 - 0.5 mm ) / 2
d91_1 | mm | MediaPoliaBuracoAltura_1
d93_1 | mm | EixoDiametro_1
d96_1 | mm | EixoDiametro_1
d97_1 | mm | Media1Comprimento_1 - MediaDiametroPolia_1 / 2 - MediaDiametroEncaixeDistal_1 / 2
d106_1 | mm | BuracoPrenderFio_1
d107_1 | mm | ProximalDiametroPolia_1 / 2 - 1 mm
d64_1 | mm | ProximalLargura_1 + 1 mm
d65_1 | deg | 0.0 deg
d68_1 | mm | ProximalLargura_1 + 1 mm
d69_1 | deg | 0.0 deg
d92_1 | deg | 360.0 deg
d94_1 | mm | -MediaLargura_1
d95_1 | deg | 0.0 deg
d98_1 | mm | -MediaLargura_1
d99_1 | deg | 0.0 deg
d100_1 |  | 1
d101_1 | mm | EixoFillet_1
d102_1 |  | 1
d103_1 | mm | FilletExternoCorpo_1
d104_1 |  | 1
d105_1 | mm | FilletExternoPolia_1
d108_1 | mm | -MediaLargura_1
d109_1 | deg | 0.0 deg
d110_1 |  | 1
d111_1 | mm | FilletExternoPolia_1
d1_1 | mm | MediaDiametroPolia_1
d38_1 | mm | ProximalDiametroPolia_1
d58_1 | mm | EixoDiametro_1
d70_1 | mm | ProximalDiametroEncaixeMedio_1
d71_1 | mm | EixoDiametro_1
d72_1 | mm | Proximal2Comprimento - ProximalDiametroPolia_1 / 2 - ProximalDiametroEncaixeMedio_1 / 2
d73_1 | mm | ProximalBarrigaExpessura_1
d74_1 | mm | ProximalOffsetBarriga_1
d75_1 | mm | ProximalOffsetBarriga_1
d46_1 | mm | ProximalLargura_1
d47_1 | deg | 0.0 deg
d48_1 | mm | ProximalDiametroBuracoPolia_1
d49_1 | mm | ProximalPoliaBuracoAltura_1
d50_1 | mm | 100 mm
d51_1 | mm | ProximalLargura_1 / 2
d81_1 | mm | BuracoPrenderFio_1
d82_1 | mm | ProximalDiametroPolia_1 / 2 - BuracoPrenderFio_1 / 2 - 0.5 mm
d52_1 | deg | 360.0 deg
d62_1 |  | 1
d63_1 | mm | EixoFillet_1
d76_1 |  | 1
d77_1 | mm | FilletExternoPolia_1
d78_1 |  | 1
d79_1 | mm | FilletExternoCorpo_1
d83_1 | mm | -ProximalLargura_1
d84_1 | deg | 0.0 deg

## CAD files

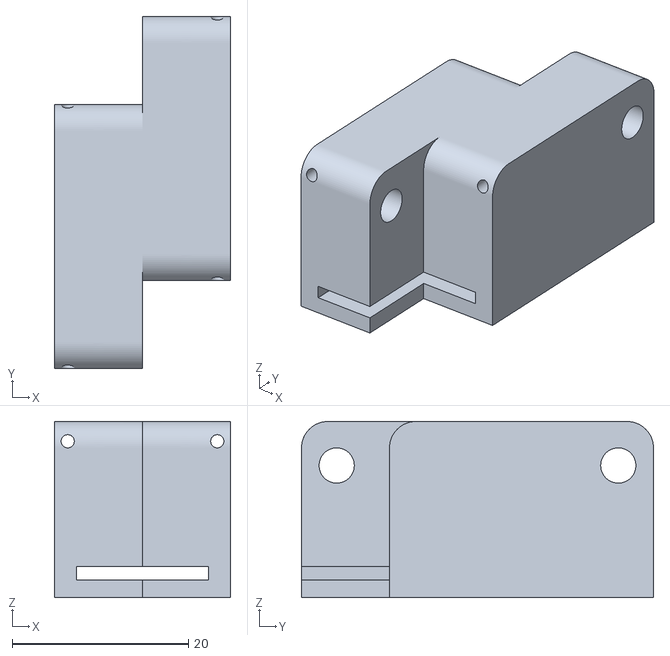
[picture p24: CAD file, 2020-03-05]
Eng/Impressão/D11.stl
20.0 x 40.0 x 20.0

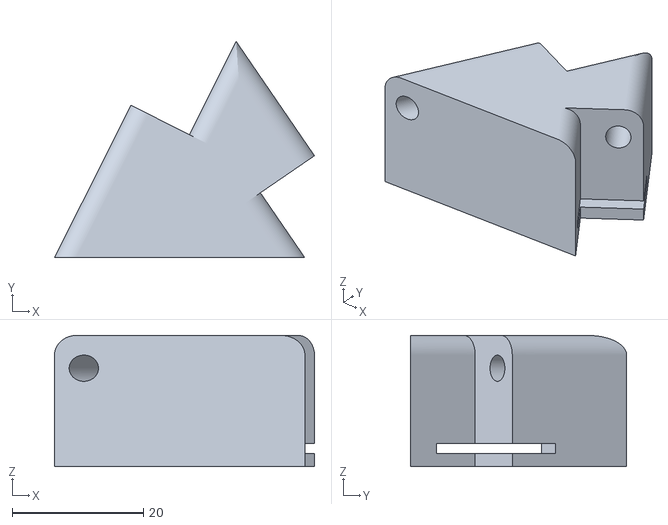
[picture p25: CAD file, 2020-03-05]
Eng/Impressão/D51.stl
39.7 x 33.0 x 20.0

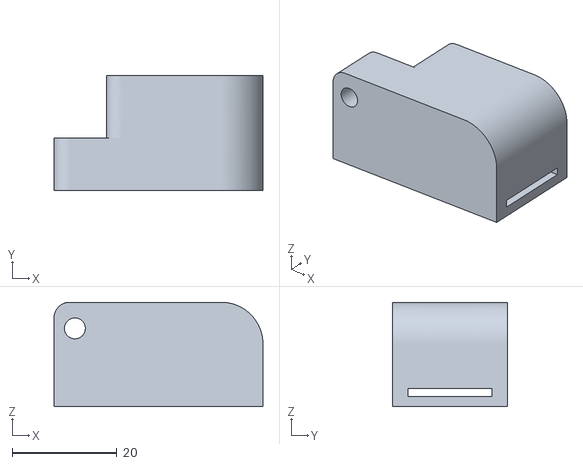
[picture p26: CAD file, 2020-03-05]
Eng/Impressão/D53.stl
40.0 x 22.0 x 20.0

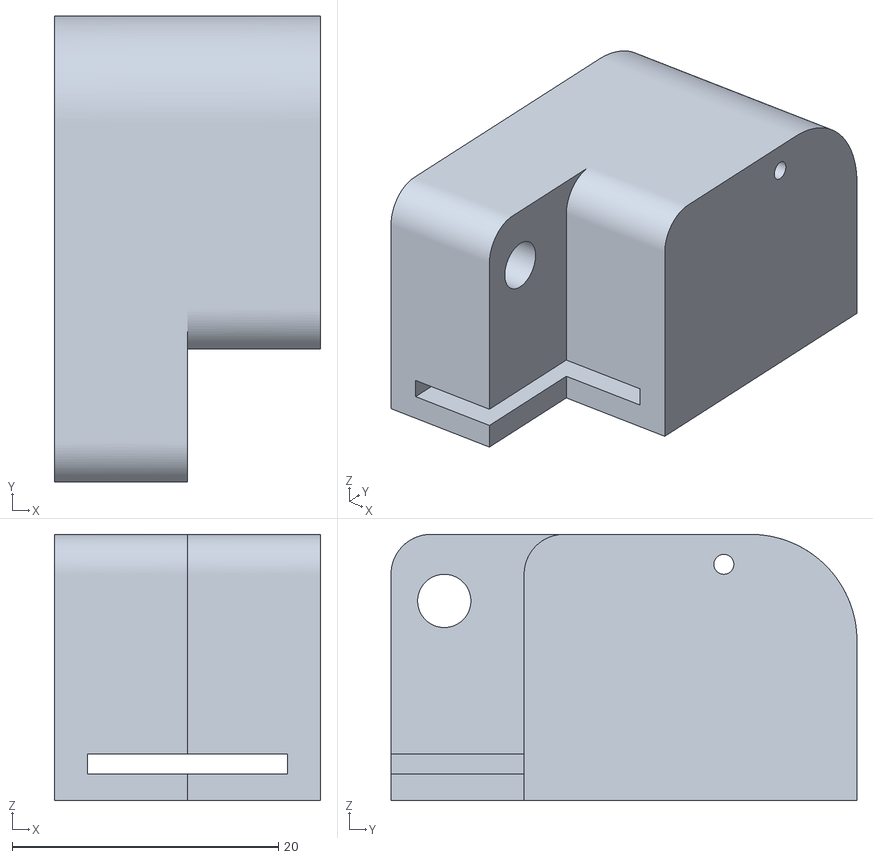
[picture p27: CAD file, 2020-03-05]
Eng/Impressão/D13.stl
20.0 x 35.0 x 20.0

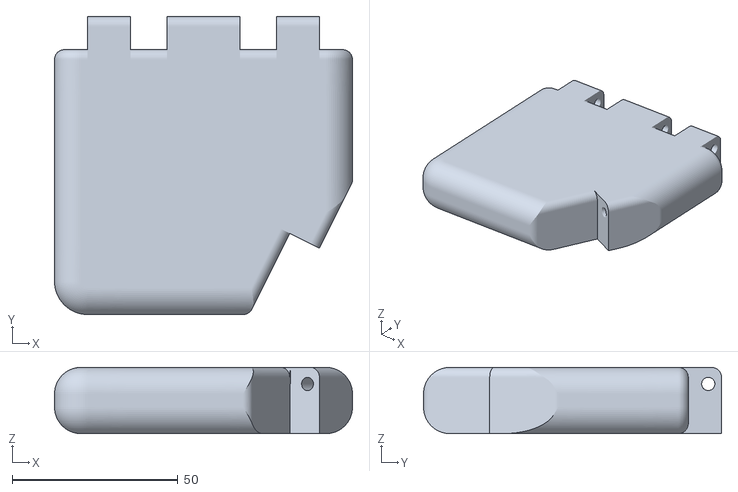
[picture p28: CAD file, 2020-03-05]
Eng/Impressão/Palma.stl
90.0 x 90.0 x 20.0

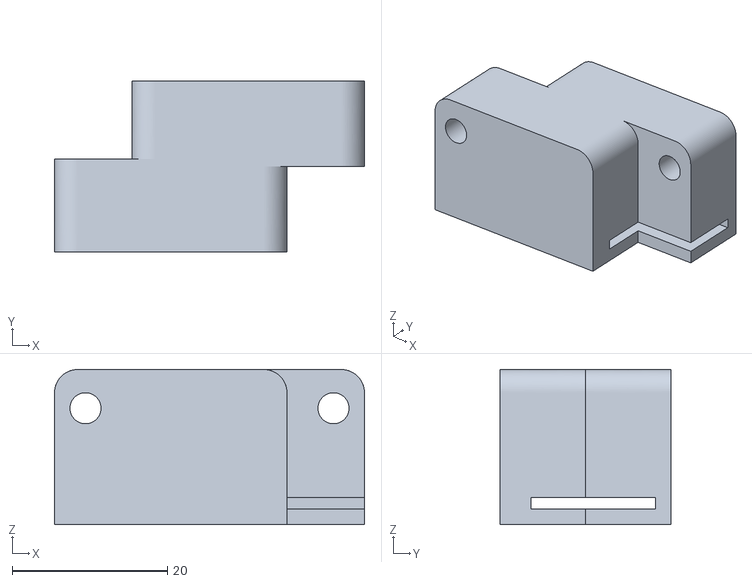
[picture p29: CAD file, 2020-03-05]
Eng/Impressão/D52.stl
40.0 x 22.0 x 20.0

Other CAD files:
Eng/Impressão/D12.stl
Eng/Modelos/D1/D1 novo.iam
Eng/Modelos/D1/D11.ipt
Eng/Modelos/D1/D12.ipt
Eng/Modelos/D1/D13.ipt
Eng/Modelos/D5/Component1.ipt
Eng/Modelos/D5/Component2.ipt
Eng/Modelos/D5/Component3.ipt
Eng/Modelos/D5/D5 v2.iam
Eng/Modelos/Palma/Palma.iam
Eng/Modelos/Palma/Palma.ipt
Eng/Modelos/Tudo/Component1.ipt
Eng/Modelos/Tudo/Component1_1.ipt
Eng/Modelos/Tudo/Component1_2.ipt
Eng/Modelos/Tudo/Component2.ipt
Eng/Modelos/Tudo/Component2_1.ipt
Eng/Modelos/Tudo/Component2_2.ipt
Eng/Modelos/Tudo/Component3.ipt
Eng/Modelos/Tudo/Component3_1.ipt
Eng/Modelos/Tudo/Component3_2.ipt
Eng/Modelos/Tudo/D1 novo v9.iam
Eng/Modelos/Tudo/D11.ipt
Eng/Modelos/Tudo/D11_1.ipt
Eng/Modelos/Tudo/D12.ipt
Eng/Modelos/Tudo/D12_1.ipt
Eng/Modelos/Tudo/D13.ipt
Eng/Modelos/Tudo/D13_1.ipt
Eng/Modelos/Tudo/D2 v10.iam
Eng/Modelos/Tudo/D3 v6.iam
Eng/Modelos/Tudo/D4 v6.iam
Eng/Modelos/Tudo/D5 v2 v12.iam
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

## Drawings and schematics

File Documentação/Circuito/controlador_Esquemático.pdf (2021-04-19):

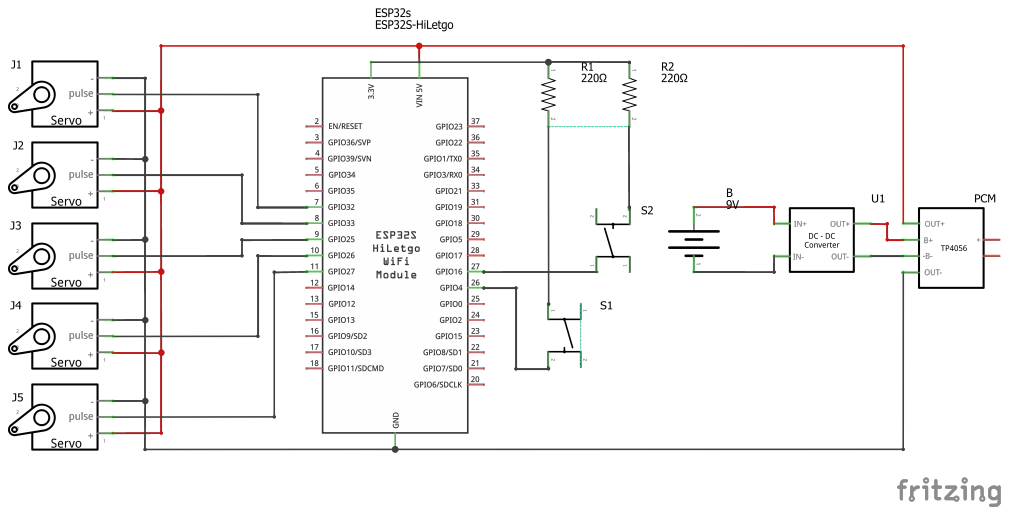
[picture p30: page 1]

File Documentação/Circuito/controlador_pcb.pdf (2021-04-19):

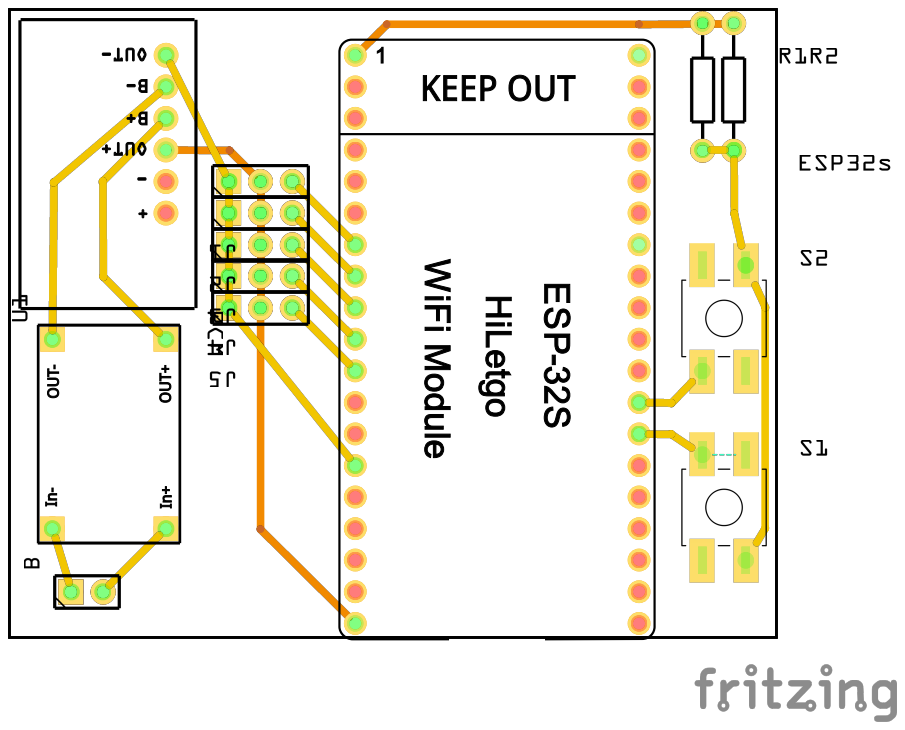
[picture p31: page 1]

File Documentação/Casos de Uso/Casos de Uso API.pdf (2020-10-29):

## Casos de Uso API

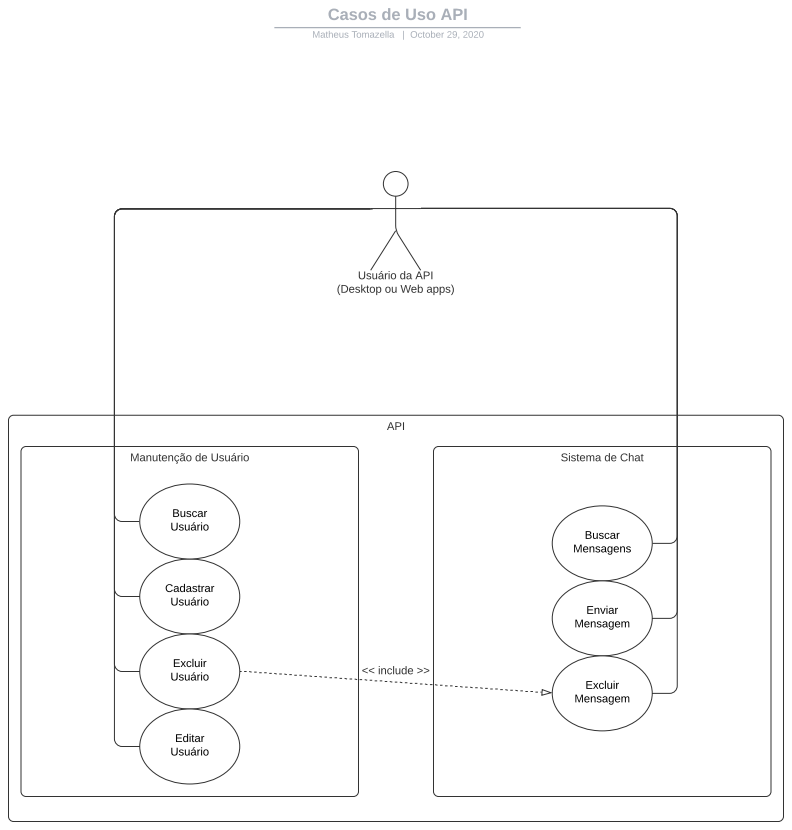
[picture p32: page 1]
API; Cadastrar Usuário; Buscar Usuário; Excluir Usuário; Editar Usuário; Buscar Mensagens; Enviar Mensagem; Excluir Mensagem; << include >>

Matheus Tomazella | October 29, 2020

Usuário da API
(Desktop ou Web apps)

Manutenção de Usuário

Sistema de Chat

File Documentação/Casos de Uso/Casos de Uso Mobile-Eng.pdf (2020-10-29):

## Casos de Uso Mobile-Eng

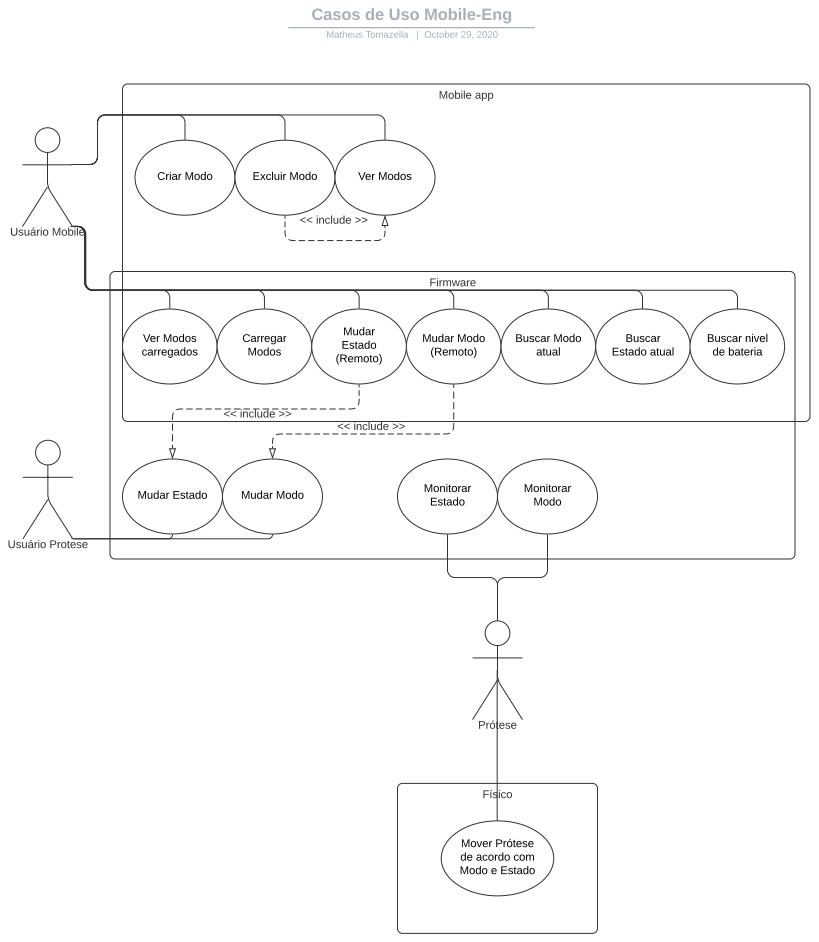
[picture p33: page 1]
Mobile app; Usuário Mobile; Criar Modo; Excluir Modo; Ver Modos; << include >>; Ver Modos carregados; Firmware; Carregar Modos; Mudar Estado; Mudar Modo; Mudar Modo (Remoto); Mudar Estado (Remoto); Buscar Modo atual; Buscar Estado atual; Buscar nivel de bateria; Monitorar Estado; Usuário Protese; Prótese; Físico; Monitorar Modo

Matheus Tomazella | October 29, 2020

Mover Prótese
de acordo com
Modo e Estado

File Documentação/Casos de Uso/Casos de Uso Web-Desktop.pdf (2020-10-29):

### Web app + API + Desktop app ( Sistema )

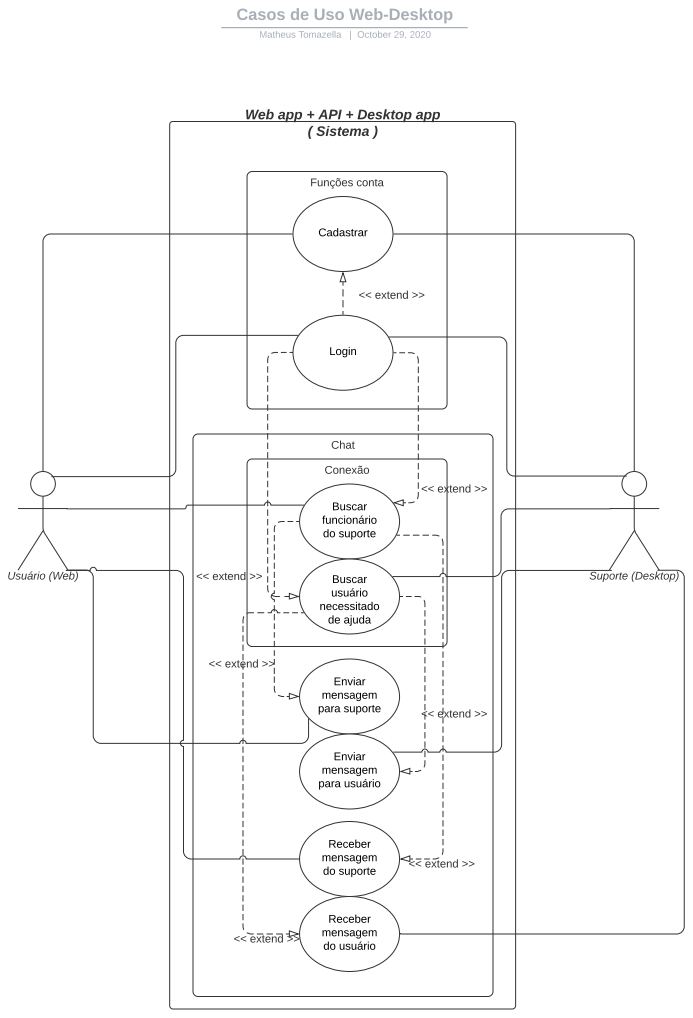
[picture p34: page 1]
Usuário (Web); Suporte (Desktop); Login; Cadastrar; << extend >>; Funções conta; Buscar funcionário do suporte; Chat; Conexão; Buscar usuário necessitado de ajuda; Enviar mensagem; para suporte; para usuário; Receber mensagem; do suporte; do usuário

Casos de Uso Web-Desktop

Matheus Tomazella | October 29, 2020

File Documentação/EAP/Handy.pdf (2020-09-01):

# Handy

Planejamento | Design

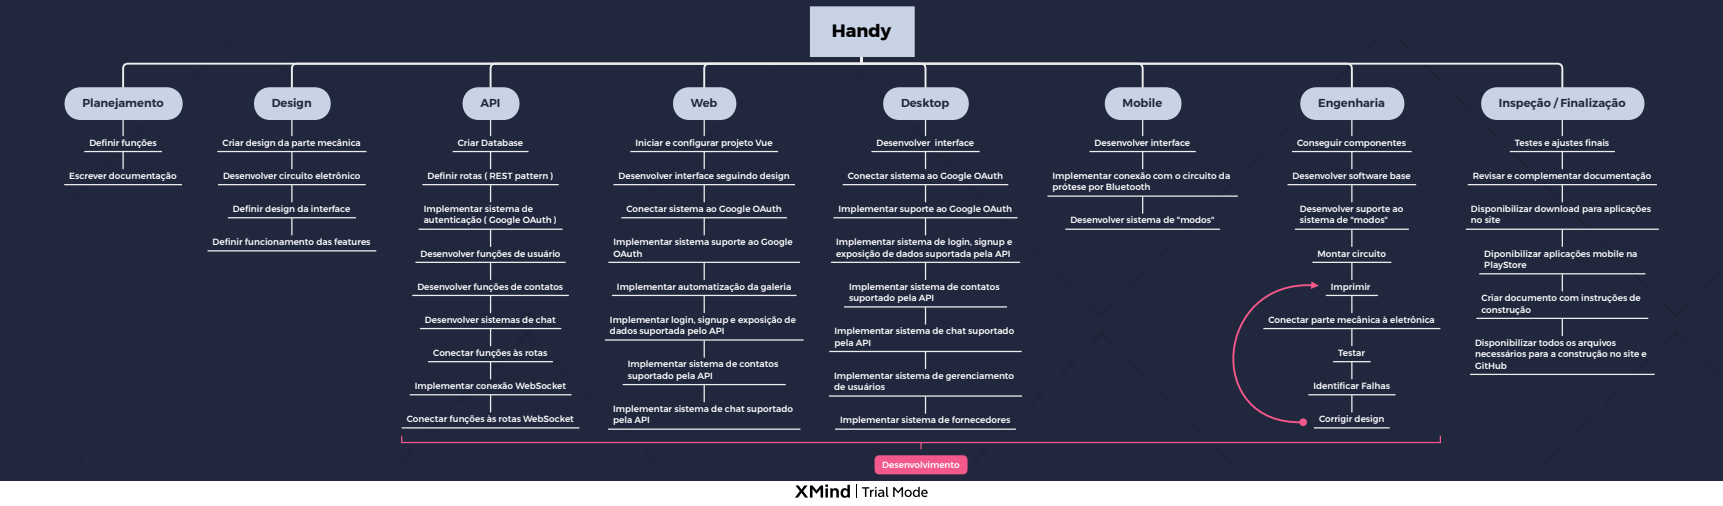
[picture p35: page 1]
Definir funções; Escrever documentação; Web; Desktop; Mobile; Engenharia; Desenvolvimento; API; Inspeção / Finalização; Criar Database; Desenvolver interface; Conseguir componentes; Montar circuito; Imprimir; Testar; Identificar Falhas; Corrigir design

Criar design da parte mecânica

Iniciar e configurar projeto Vue

Testes e ajustes finais

Desenvolver circuito eletrônico

Definir rotas ( REST pattern )

Desenvolver interface seguindo design

Conectar sistema ao Google OAuth

Implementar conexão com o circuito da
prótese por Bluetooth

Desenvolver software base

Revisar e complementar documentação

Definir design da interface

Implementar sistema de
autenticação ( Google OAuth )

Implementar suporte ao Google OAuth

Desenvolver suporte ao
sistema de "modos"

Disponibilizar download para aplicações
no site

Desenvolver sistema de "modos"

Definir funcionamento das features

Implementar sistema suporte ao Google
OAuth

Implementar sistema de login, signup e
exposição de dados suportada pela API

Desenvolver funções de usuário

Diponibilizar aplicações mobile na
PlayStore

Desenvolver funções de contatos

Implementar automatização da galeria

Implementar sistema de contatos
suportado pela API

Criar documento com instruções de
construção

Desenvolver sistemas de chat

Implementar login, signup e exposição de
dados suportada pelo API

Conectar parte mecânica à eletrônica

Implementar sistema de chat suportado
pela API

Disponibilizar todos os arquivos
necessários para a construção no site e
GitHub

Conectar funções às rotas

Implementar sistema de gerenciamento
de usuários

Implementar conexão WebSocket

Conectar funções às rotas WebSocket

Implementar sistema de fornecedores

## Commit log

2020-03-14 Mudança de nome de arquivo
2021-04-19 Atualizações
    [ConjuntoAtuador.fzz, ConjuntoDeControle.fzz, Cronograma.ods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]
